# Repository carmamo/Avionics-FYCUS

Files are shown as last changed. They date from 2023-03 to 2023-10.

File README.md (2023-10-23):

<!-- Improved compatibility of back to top link: See: https://github.com/othneildrew/Best-README-Template/pull/73 -->

<!--
*** Thanks for checking out the Best-README-Template. If you have a suggestion
*** that would make this better, please fork the repo and create a pull request
*** or simply open an issue with the tag "enhancement".
*** Don't forget to give the project a star!
*** Thanks again! Now go create something AMAZING! :D
-->

<!-- PROJECT SHIELDS -->
<!--
*** I'm using markdown "reference style" links for readability.
*** Reference links are enclosed in brackets [ ] instead of parentheses ( ).
*** See the bottom of this document for the declaration of the reference variables
*** for contributors-url, forks-url, etc. This is an optional, concise syntax you may use.
*** https://www.markdownguide.org/basic-syntax/#reference-style-links
-->
[][contributors-url]
[][forks-url]
[][stars-url]
[][issues-url]
[][license-url]
[][linkedin-url]

<!-- PROJECT LOGO -->
<br />
<div align="center">
  <a href="https://github.com/carmamo/Avionics-FYCUS/">
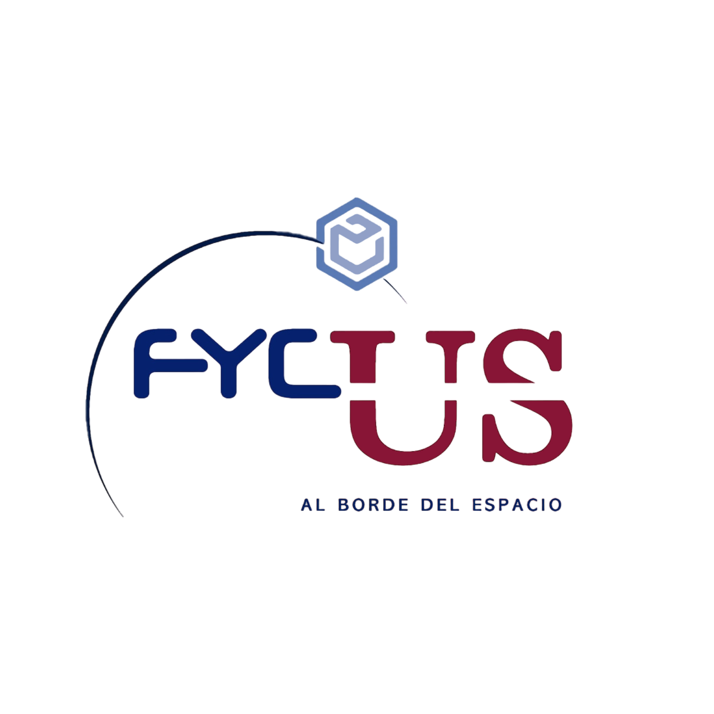
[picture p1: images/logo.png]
    
  </a>

<h3 align="center">Avionics FYCUS</h3>

  <p align="center">
    Hardware and Firmware for a 3U Cubesat
    <br />
    <a href="https://github.com/carmamo/Avionics-FYCUS"><strong>Explore the docs »</strong></a>
    <br />
    <br />
    <a href="https://github.com/carmamo/Avionics-FYCUS">View Demo</a>
    ·
    <a href="https://github.com/carmamo/Avionics-FYCUS/issues">Report Bug</a>
    ·
    <a href="https://github.com/carmamo/Avionics-FYCUS/issues">Request Feature</a>
  </p>
</div>

<!-- TABLE OF CONTENTS -->
<details>
  <summary>Table of Contents</summary>
  <ol>
    <li>
      <a href="#about-the-project">About The Project</a>
      <ul>
        <li><a href="#built-with">Built With</a></li>
      </ul>
    </li>
    <li>
      <a href="#getting-started">Getting Started</a>
      <ul>
        <li><a href="#prerequisites">Prerequisites</a></li>
        <li><a href="#installation">Installation</a></li>
      </ul>
    </li>
    <li><a href="#usage">Usage</a></li>
    <li><a href="#roadmap">Roadmap</a></li>
    <li><a href="#contributing">Contributing</a></li>
    <li><a href="#license">License</a></li>
    <li><a href="#contact">Contact</a></li>
    <li><a href="#acknowledgments">Acknowledgments</a></li>
  </ol>
</details>

<!-- ABOUT THE PROJECT -->
## About The Project
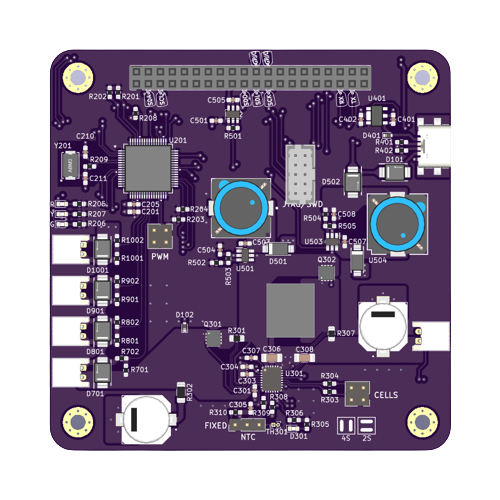
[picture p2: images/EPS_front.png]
Product front Screen Shot

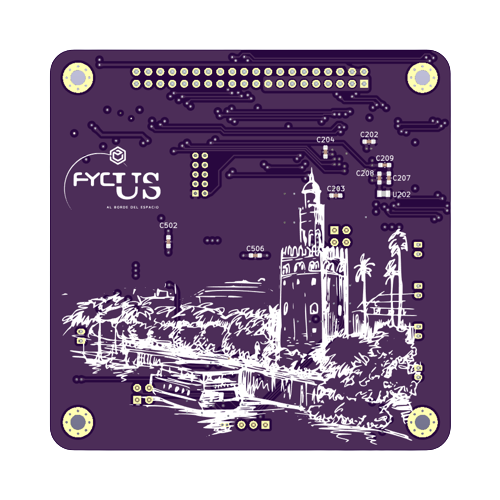
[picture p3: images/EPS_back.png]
Product back Screen Shot

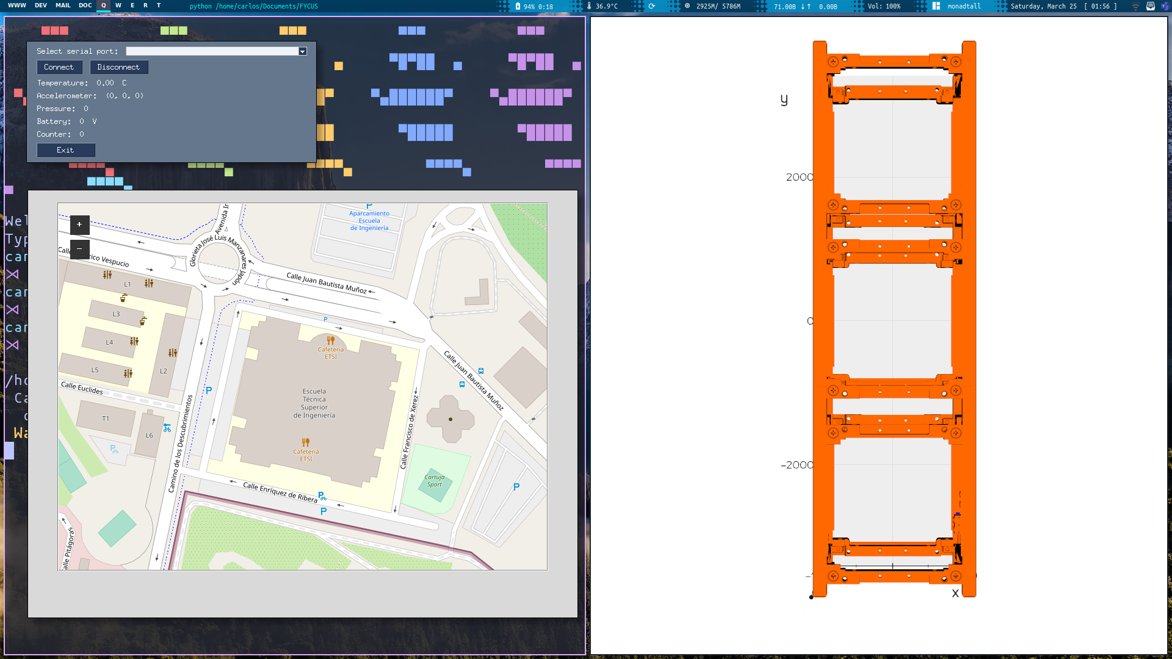
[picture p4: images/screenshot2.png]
Product gui Screen Shot
[][gui-screenshot]

This project involves the creation of the PCB and firmware for a 3U CubeSat, in collaboration with FYCUS, a team of passionate students at the University of Seville. Our mission is to design, manufacture and operate small satellites, and this project is a critical step in achieving that goal.

Our team will be responsible for the design and implementation of the PCB and firmware, which are essential components of the CubeSat's operation.

<p align="right">(<a href="#readme-top">back to top</a>)</p>

### Built With







<p align="right">(<a href="#readme-top">back to top</a>)</p>

<!-- GETTING STARTED -->
## Getting Started

This is an example of how you may give instructions on setting up your project locally.
To get a local copy up and running follow these simple example steps.

### Prerequisites

This is an example of how to list things you need to use the software and how to install them.
* npm
  ```sh
  npm install npm@latest -g
  ```

### Installation

1. Get a free API Key at [https://example.com](https://example.com)
2. Clone the repo
   ```sh
   git clone https://github.com/carmamo/Avionics-FYCUS.git
   ```
3. Install NPM packages
   ```sh
   npm install
   ```
4. Enter your API in `config.js`
   ```js
   const API_KEY = 'ENER YOUR API';
   ```

<p align="right">(<a href="#readme-top">back to top</a>)</p>

<!-- USAGE EXAMPLES -->
## Usage

Use this space to show useful examples of how a project can be used. Additional screenshots, code examples and demos work well in this space. You may also link to more resources.

_For more examples, please refer to the [Documentation](https://example.com)_

<p align="right">(<a href="#readme-top">back to top</a>)</p>

<!-- ROADMAP -->
## Roadmap

- [ ] Feature 1
- [ ] Feature 2
- [ ] Feature 3
    - [ ] Nested Feature

See the [open issues](https://github.com/carmamo/Avionics-FYCUS/issues) for a full list of proposed features (and known issues).

<p align="right">(<a href="#readme-top">back to top</a>)</p>

<!-- CONTRIBUTING -->
## Contributing

Contributions are what make the open source community such an amazing place to learn, inspire, and create. Any contributions you make are **greatly appreciated**.

If you have a suggestion that would make this better, please fork the repo and create a pull request. You can also simply open an issue with the tag "enhancement".
Don't forget to give the project a star! Thanks again!

1. Fork the Project
2. Create your Feature Branch (`git checkout -b feature/AmazingFeature`)
3. Commit your Changes (`git commit -m 'Add some AmazingFeature'`)
4. Push to the Branch (`git push origin feature/AmazingFeature`)
5. Open a Pull Request

<p align="right">(<a href="#readme-top">back to top</a>)</p>

<!-- LICENSE -->
## License

Distributed under the MIT License. See `LICENSE.txt` for more information.

<p align="right">(<a href="#readme-top">back to top</a>)</p>

<!-- CONTACT -->
## Contact

Your Name - [@twitter_handle](https://twitter.com/twitter_handle) - email@email_client.com

Project Link: [https://github.com/carmamo/Avionics-FYCUS](https://github.com/carmamo/Avionics-FYCUS)

<p align="right">(<a href="#readme-top">back to top</a>)</p>

<!-- ACKNOWLEDGMENTS -->
## Acknowledgments

* []()
* []()
* []()

<p align="right">(<a href="#readme-top">back to top</a>)</p>

<!-- MARKDOWN LINKS & IMAGES -->
<!-- https://www.markdownguide.org/basic-syntax/#reference-style-links -->
[contributors-shield]: https://img.shields.io/github/contributors/carmamo/Avionics-FYCUS.svg?style=for-the-badge
[contributors-url]: https://github.com/carmamo/Avionics-FYCUS/graphs/contributors
[forks-shield]: https://img.shields.io/github/forks/carmamo/Avionics-FYCUS.svg?style=for-the-badge
[forks-url]: https://github.com/carmamo/Avionics-FYCUS/network/members
[stars-shield]: https://img.shields.io/github/stars/carmamo/Avionics-FYCUS.svg?style=for-the-badge
[stars-url]: https://github.com/carmamo/Avionics-FYCUS/stargazers
[issues-shield]: https://img.shields.io/github/issues/carmamo/Avionics-FYCUS.svg?style=for-the-badge
[issues-url]: https://github.com/carmamo/Avionics-FYCUS/issues
[license-shield]: https://img.shields.io/github/license/carmamo/Avionics-FYCUS.svg?style=for-the-badge
[license-url]: https://github.com/carmamo/Avionics-FYCUS/blob/master/LICENSE.txt
[linkedin-shield]: https://img.shields.io/badge/-LinkedIn-black.svg?style=for-the-badge&logo=linkedin&colorB=555
[linkedin-url]: https://www.linkedin.com/company/fycus/?originalSubdomain=es
[gui-screenshot]: images/screenshot2.png
[product-screenshot-front]: images/EPS_front.png
[product-screenshot-back]: images/EPS_back.png

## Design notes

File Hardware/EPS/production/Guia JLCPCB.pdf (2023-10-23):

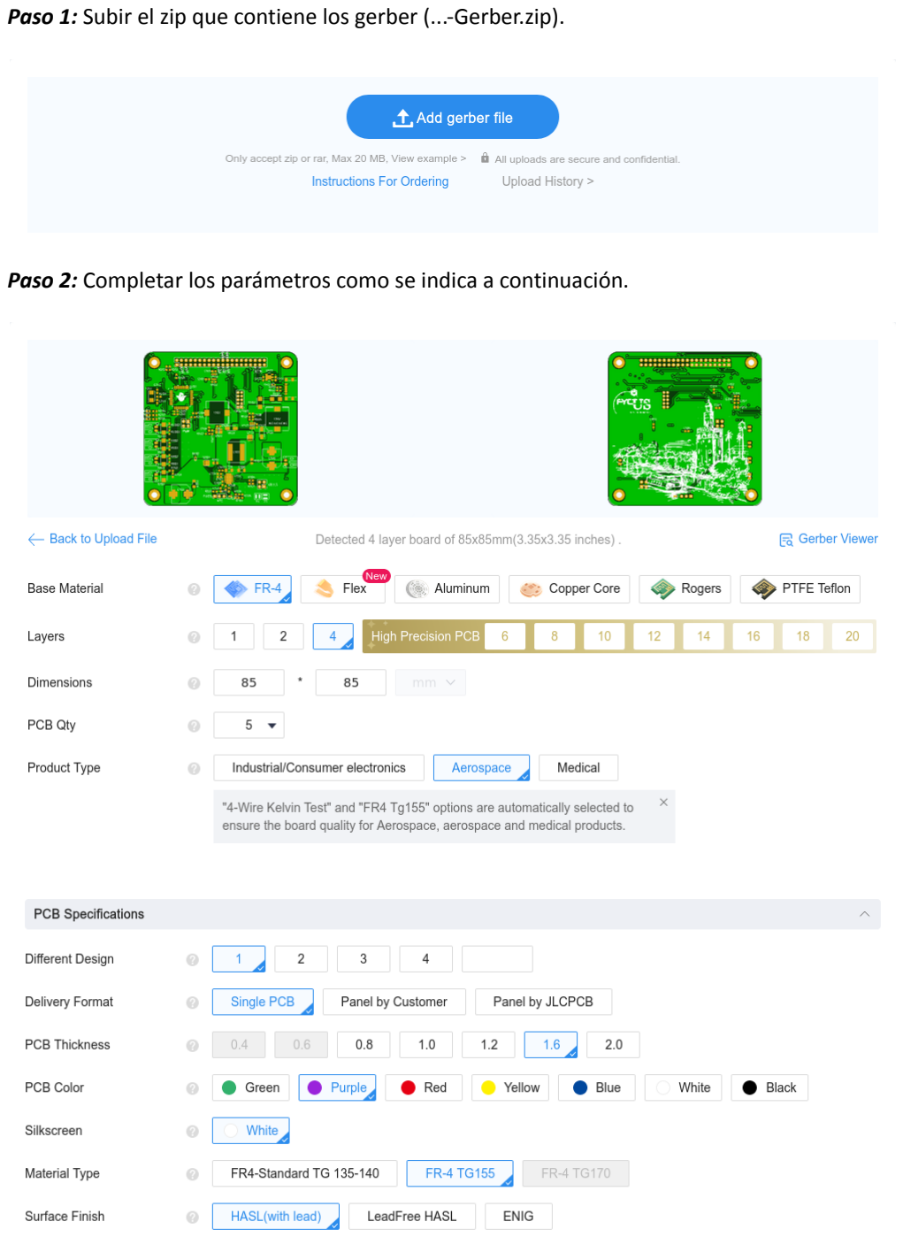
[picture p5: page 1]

Paso 1: Subir el zip que contiene los gerber (...-Gerber.zip).

Paso 2: Completar los parámetros como se indica a continuación.

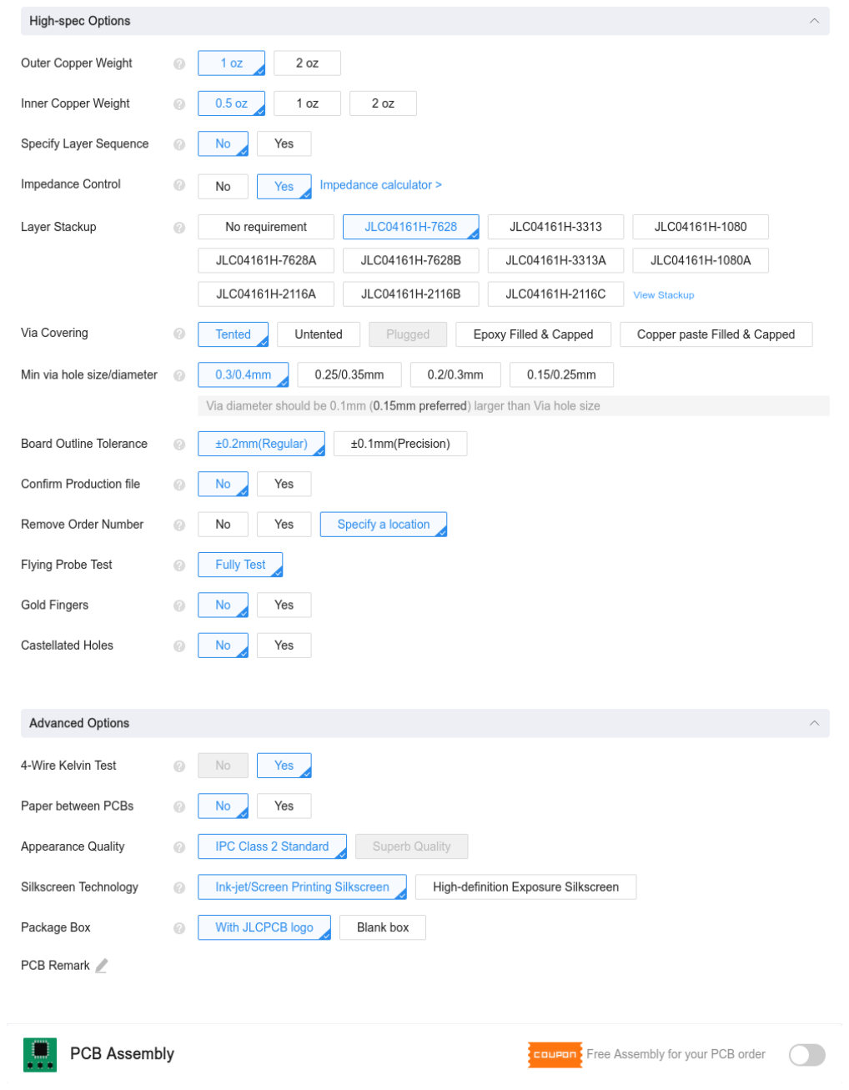
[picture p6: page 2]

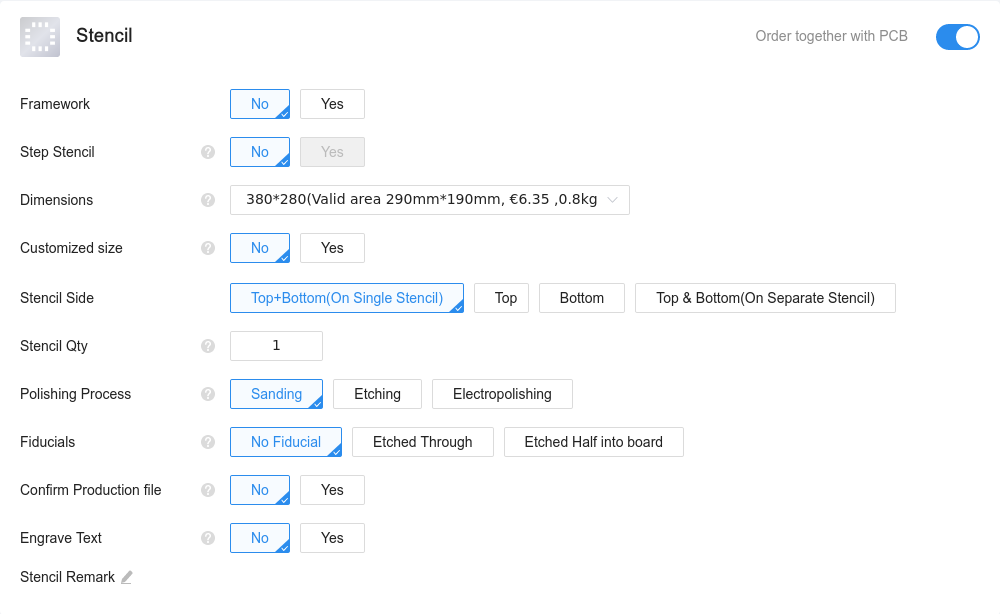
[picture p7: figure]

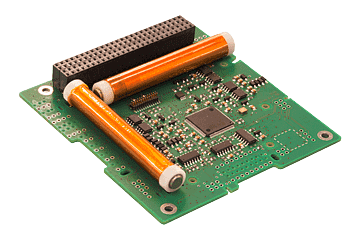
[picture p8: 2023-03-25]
images/screenshot.png

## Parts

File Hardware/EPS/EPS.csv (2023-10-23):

Component Count: | 107
Ref | Qnty | Digi-Key Part Number | Value | Cmp name | Footprint | Description
C201, C304, C401, C402, | 4 | 1276-1045-1-ND | 4.7uF | C | Capacitor_SMD:C_0603_1608Metric_Pad1.08x0.95mm_HandSolder | Unpolarized capacitor
C202, C203, C204, C205, C206, C209, C505, | 9 | 478-06036D104KAT2ACT-ND | 100nF | C | Capacitor_SMD:C_0603_1608Metric_Pad1.08x0.95mm_HandSolder | Unpolarized capacitor
C301, C303 | 9 | 1276-1935-1-ND | 100nF | C | Capacitor_SMD:C_0603_1608Metric_Pad1.08x0.95mm_HandSolder | Unpolarized capacitor
C207, C305, C501, | 3 | 1276-1034-1-ND | 1uF | C | Capacitor_SMD:C_0603_1608Metric_Pad1.08x0.95mm_HandSolder | Unpolarized capacitor
C208, C503, C507, | 3 | 399-17880-1-ND | 10nF | C | Capacitor_SMD:C_0603_1608Metric_Pad1.08x0.95mm_HandSolder | Unpolarized capacitor
C210, C211, | 2 | 1276-2134-1-ND | 6pF | C | Capacitor_SMD:C_0603_1608Metric_Pad1.08x0.95mm_HandSolder | Unpolarized capacitor
C302, C309, | 2 | 10-EEH-ZS1H151VCT-ND | 150uF | C_Polarized | EEHZS1H151V:CAP_EEHZS1H151V | Polarized capacitor
C306, C308, | 2 | 587-5960-1-ND | 10uF | C | Capacitor_SMD:C_1206_3216Metric_Pad1.33x1.80mm_HandSolder | Unpolarized capacitor
C307, | 1 | 399-C0603C223K4RAC7867CT-ND | 22nF | C | Capacitor_SMD:C_0603_1608Metric_Pad1.08x0.95mm_HandSolder | Unpolarized capacitor
C502, C506, | 2 | 490-3896-1-ND | 10uF | C | Capacitor_SMD:C_0603_1608Metric_Pad1.08x0.95mm_HandSolder | Unpolarized capacitor
C504, C508, | 2 | 1276-1274-1-ND | 22uF | C | Capacitor_SMD:C_0603_1608Metric_Pad1.08x0.95mm_HandSolder | Unpolarized capacitor
D101, D502, D701, D801, D901, D1001, | 6 | 150-LSM115JE3/TR13CT-ND | LSM115JE3_TR13 | LSM115JE3_TR13 | LSM115JE3_TR13:DIOM5436X330N | Schottky Diodes & Rectifiers Schottky
D102, | 1 | BZT585B24T-7DICT-ND | BZT585B24T-7 | D_Zener | Diode_SMD:D_SOD-523 | Zener diode
D201, | 1 | 160-1447-1-ND | LED_R | LED | LED_SMD:LED_0603_1608Metric | Light emitting diode
D202, | 1 | 160-1446-1-ND | LED_G | LED | LED_SMD:LED_0603_1608Metric | Light emitting diode
D203, | 2 | 160-1448-1-ND | LED_YL | LED | LED_SMD:LED_0603_1608Metric | Light emitting diode
D401, | 1 | 1727-3838-1-ND | PESD5V0S1BB_115 | D_TVS | Diode_SMD:D_SOD-523 | Bidirectional transient-voltage-suppression diode
D501, | 2 | B230A-FDICT-ND | B230A-13-F | B230A-13-F | B230A-13-F:DIOM5226X230N | Schottky Diode 2A 30V 0.5Vf SMA Diodes Inc B230A-13-F, SMT Schottky Diode, 30V 2A, 2-Pin DO-214AC
J201, | 1 | 1175-1627-ND | Conn_ARM_JTAG_SWD_10 | Conn_ARM_JTAG_SWD_10 | digikey-footprints:PinHeader_2x5_P1.27mm_Drill.7mm | Cortex Debug Connector, standard ARM Cortex-M SWD and JTAG interface
J401, | 1 | 2073-USB4135-GF-ACT-ND | USB_C_Receptacle_PowerOnly_6P | USB_C_Receptacle_PowerOnly_6P | Connector_USB:USB_C_Receptacle_GCT_USB4135-GF-A_6P_TopMnt_Horizontal | USB Power-Only 6P Type-C Receptacle connector
J701, J801, J901, J1001, J1101, | 50 | 455-1719-ND | Conn_01x02 | Conn_01x02 | Connector_JST:JST_PH_S2B-PH-K_1x02_P2.00mm_Horizontal
 | 50 | 455-1165-ND | PHR-2 | CONN RCPT HSG 2POS 2.00MM |  | CONN RCPT HSG 2POS 2.00MM
 | 100 | 455-2148-1-ND | SPH-002T-P0.5L | CONN SOCKET 24-28AWG CRIMP TIN |  | CONN SOCKET 24-28AWG CRIMP TIN
L301, | 1 | 4652-XAL1060-472MEC-ND / 240-MHE06034R7M-10CT-ND | 4.7uH | L | XAL1060-222MEB:XAL1060222MEB | Inductor
L501, | 1 | 445-SLF12555T-100M3R4-PFCT-ND | 10uH | L | SLF12555T-100M3R4-PF:SLF12555T | Inductor
L502, | 1 | 445-174404-1-ND | 15uH | L | SLF12565T-150M4R2-PF:SLF12565 | Inductor
Q301, Q302, | 2 | RQ3G100GNTBCT-ND | RQ3G100GNTB | RQ3G100GNTB | RQ3G100GNTB:RQ3G100GNTB | Nch 40V 27A Power MOSFET
R201, R202, R203, R204, | 4 | 1712-CPF-A-0603B4K7ECT-ND | 4.7k | R | Resistor_SMD:R_0603_1608Metric_Pad0.98x0.95mm_HandSolder | Resistor
R205, R206, | 2 | A102228CT-ND | 1.3k | R | Resistor_SMD:R_0603_1608Metric_Pad0.98x0.95mm_HandSolder | Resistor
R207, R305, | 2 | 1712-CPF-A-0603B1K2ECT-ND | 1.2k | R | Resistor_SMD:R_0603_1608Metric_Pad0.98x0.95mm_HandSolder | Resistor
R208, R309, R310, R501, | 4 | A121523CT-ND | 10k | R | Resistor_SMD:R_0603_1608Metric_Pad0.98x0.95mm_HandSolder | Resistor
R209, R702, R802, R902, R1002, | 5 | A129694CT-ND | 3.3k | R | Resistor_SMD:R_0603_1608Metric_Pad0.98x0.95mm_HandSolder | Resistor
R301, R307, | 2 | 2019-UR73D2ATTD10L0FCT-ND | 10m | R | Resistor_SMD:R_0805_2012Metric_Pad1.20x1.40mm_HandSolder | Resistor
R302, | 1 | 2019-RK73H2HTTE2R49FCT-ND | 2.49 | R | Resistor_SMD:R_2010_1608Metric_Pad0.98x0.95mm_HandSolder | Resistor
R303, R304, R306, R502, | 4 | 408-2101-1-ND | 100k | R | Resistor_SMD:R_0603_1608Metric_Pad0.98x0.95mm_HandSolder | Resistor
R308, | 1 | 541-63.4KHCT-ND | 63.4k | R | Resistor_SMD:R_0603_1608Metric_Pad0.98x0.95mm_HandSolder | Resistor
R401, R402, | 2 | RG16P5.1KBCT-ND | 5.1k | R | Resistor_SMD:R_0603_1608Metric_Pad0.98x0.95mm_HandSolder | Resistor
R503, | 1 | RG16P32.4KBCT-ND | 32.4k | R | Resistor_SMD:R_0603_1608Metric_Pad0.98x0.95mm_HandSolder | Resistor
R504, | 1 | RG16P91.0KBCT-ND | 91k | R | Resistor_SMD:R_0603_1608Metric_Pad0.98x0.95mm_HandSolder | Resistor
R505, | 1 | RMCF0603FT17K4CT-ND | 17.4k | R | Resistor_SMD:R_0603_1608Metric_Pad0.98x0.95mm_HandSolder | Resistor
R701, R801, R901, R1001, | 4 | A129703CT-ND | 18k | R | Resistor_SMD:R_0603_1608Metric_Pad0.98x0.95mm_HandSolder | Resistor
TH301, | 1 | 2259-BN35-3H103FB-50-ND | 10k | Thermistor_NTC | Connector_PinHeader_1.00mm:PinHeader_1x02_P1.00mm_Vertical | Temperature dependent resistor, negative temperature coefficient
U201, | 1 | 497-STM32L431RCT6CT-ND | STM32L431RCT | STM32L431RCT | STM32L431RCT:LQFP-64
U202, | 1 | 240-2399-1-ND | HZ0805E601R-10 | HZ0805E601R-10 | HZ0805E601R-10:BEADC2012X90N | FERRITE BEAD 600 OHM 0805 1LN
U301, | 1 | LTC4162EUFD-L41M#PBF-ND | LTC4162EUFD-L41M#PBF | LTC4162EUFD-L41#PBF | LTC4162EUFD-L41_PBF:QFN50P500X400X80-29N
U301, | 1 | 505-LTC4162EUFD-LADM#PBF-ND | LTC4162EUFD-LADM#PBF | LTC4162EUFD-L41#PBF | LTC4162EUFD-L41_PBF:QFN50P500X400X80-29N
U401, | 1 | AP7361C-25Y5-13DICT-ND | AP7361C-33Y5-13 | AP7361C-25Y5-13 | AP7361C-25Y5-13:AP7361C25Y513 | LDO Voltage Regulators 1A LDO Reg w/Enable 2.5V 6.5Vin 800mW
U501, U503, | 2 | 1028-RT8258GECT-ND | RT8258GE | RT8258GE | RT8258GE:SOT94P279X130-6N | IC REG BUCK ADJ 1.2A SOT23-6
U502, | 1 | 296-34970-1-ND | TPS27081ADDCR | TPS27081ADDCR | digikey-footprints:SOT-23-6 | IC LOAD SW HIGH SIDE 6SOT
Y201, | 1 | 644-1132-1-ND | NX5032GA-8.000M-STD-CSU-1 | NX5032GA-8.000M-STD-CSU-1 | NX5032GA-8.000M:XTAL_NX5032_NDK

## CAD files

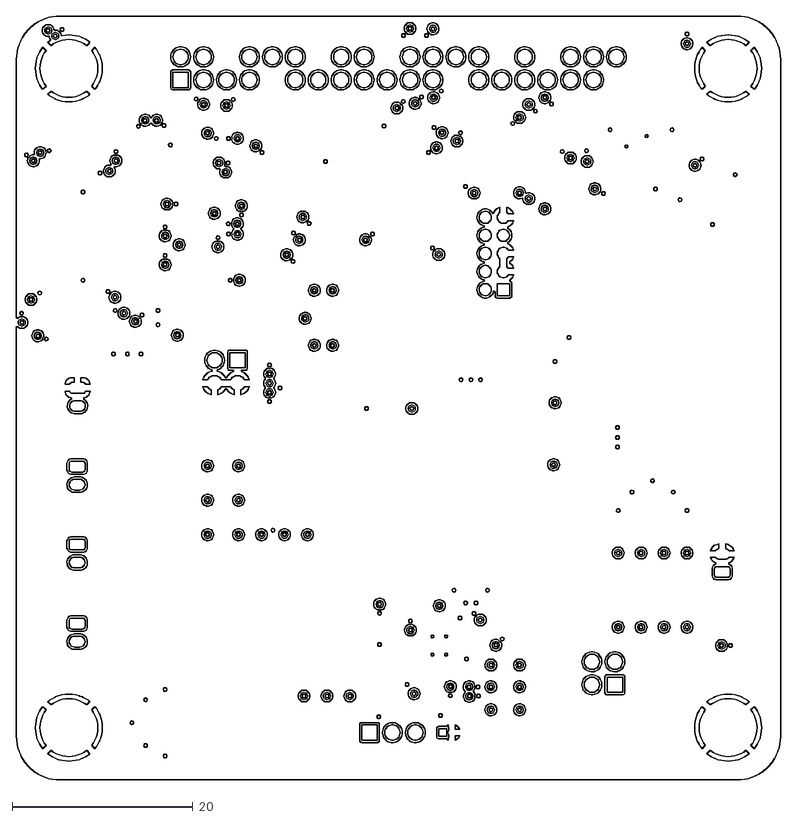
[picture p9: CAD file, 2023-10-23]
Hardware/EPS/production/EPS-GND2_Cu.dxf
84.6 x 84.6

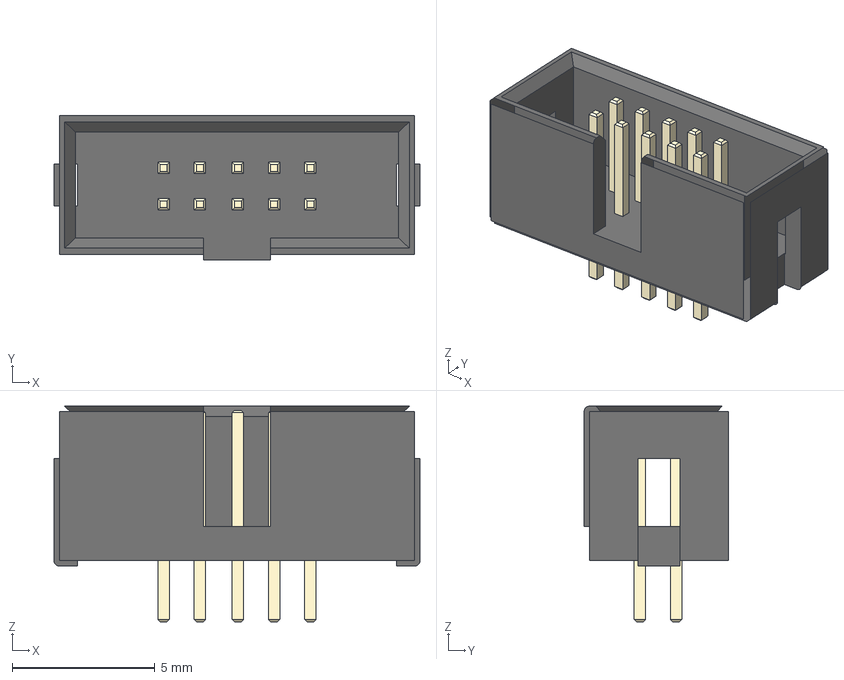
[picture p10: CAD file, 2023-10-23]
Hardware/KiCAD_Libs/3220-10-0100-00/3D/3220-10-0100-00.stp
12.8 x 5.24 x 7.55 mm
Linear Pattern 01
Pins:1

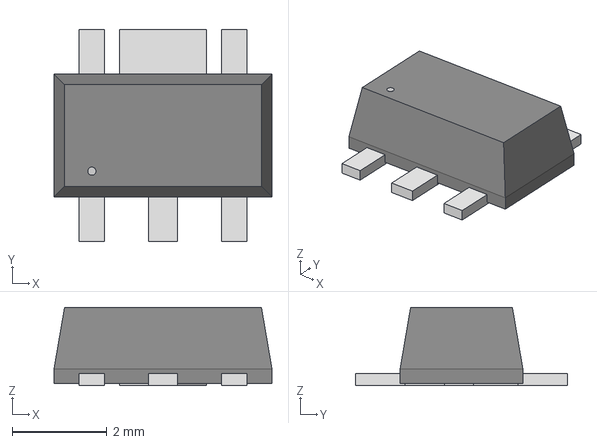
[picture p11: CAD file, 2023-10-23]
Hardware/KiCAD_Libs/AP7361C-25Y5-13/3D/SOT89-5_DIO.step
4.60 x 4.47 x 1.65 mm

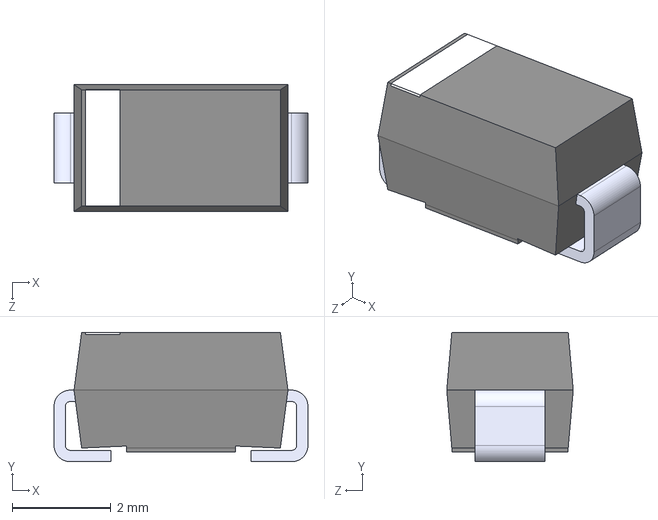
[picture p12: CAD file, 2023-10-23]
Hardware/KiCAD_Libs/B230A-13-F/3D/B340A-13-F.STEP
5.14 x 2.62 x 2.56 mm

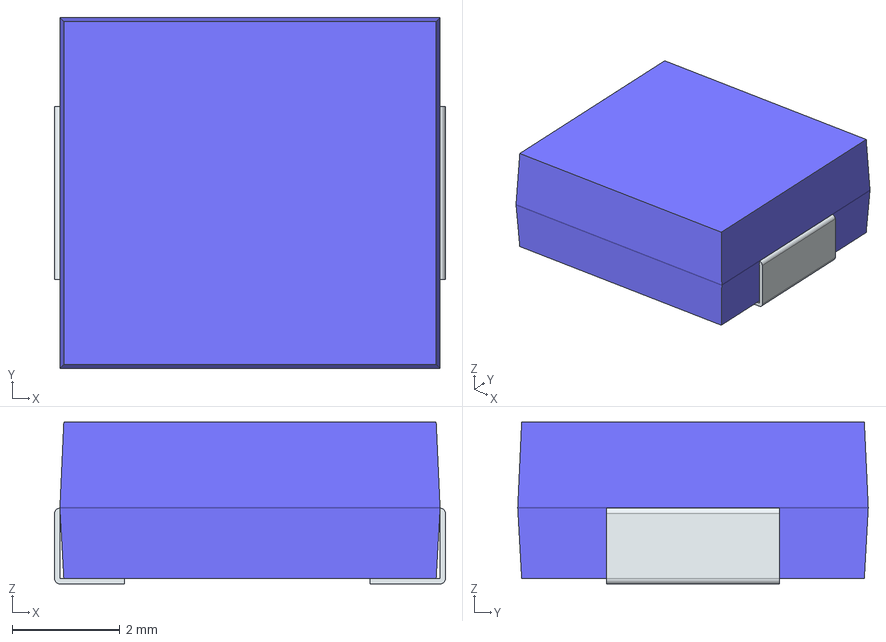
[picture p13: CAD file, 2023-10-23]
Hardware/KiCAD_Libs/CDMC6D28NP-2R2MC/3D/CDMC6D28NP-2R2MC.stp
7.25 x 6.50 x 3.00 mm
FilletPin1
FilletPin2

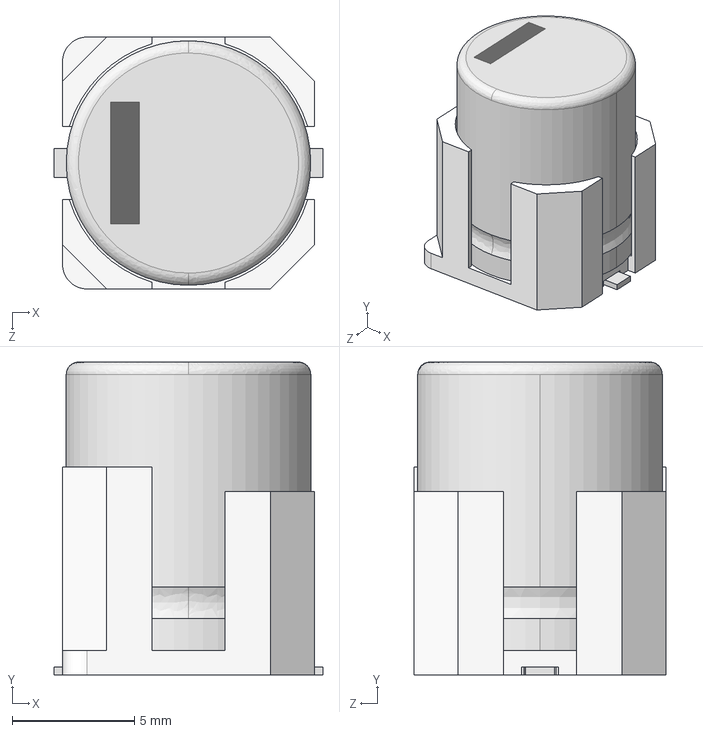
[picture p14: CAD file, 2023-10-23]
Hardware/KiCAD_Libs/EEHZS1H151V/3D/EEHZS1H151V.STEP
11.0 x 12.8 x 10.3 mm

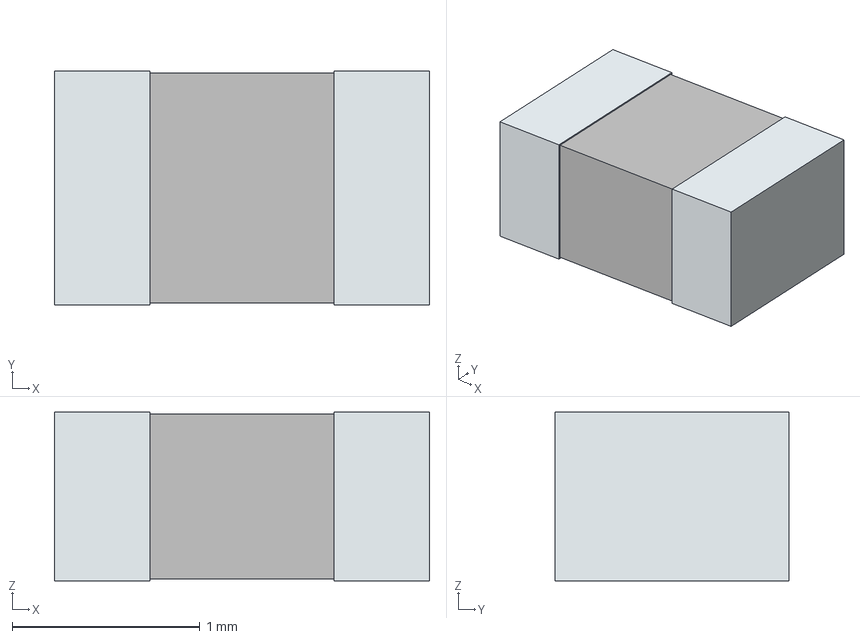
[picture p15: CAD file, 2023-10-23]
Hardware/KiCAD_Libs/HZ0805E601R-10/3D/HZ0805E601R-10.stp
2.00 x 1.25 x 0.9 mm
term1
term2

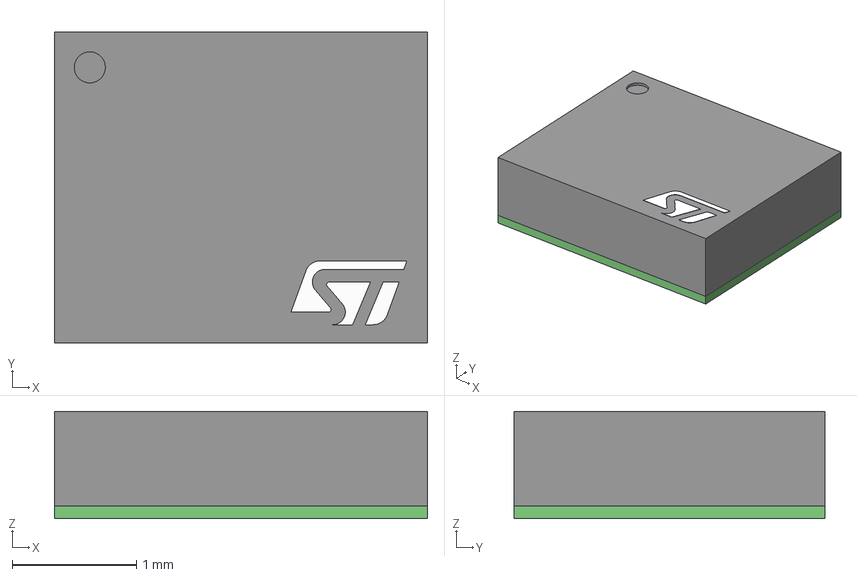
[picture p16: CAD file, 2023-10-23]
Hardware/KiCAD_Libs/IMU_LSM6DSOTR/eec.models/STMicroelectronics_-_LSM6DSOTR.step
3.00 x 2.50 x 0.863 mm
base
logo
terminals

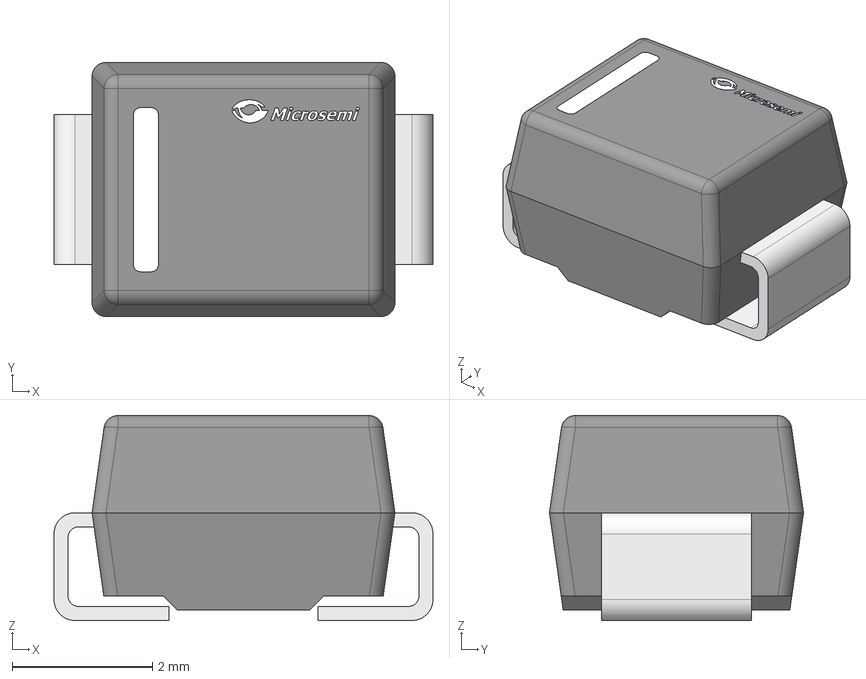
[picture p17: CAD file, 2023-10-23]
Hardware/KiCAD_Libs/LSM115JE3_TR13/3D/TR13.step
5.40 x 3.62 x 2.92 mm

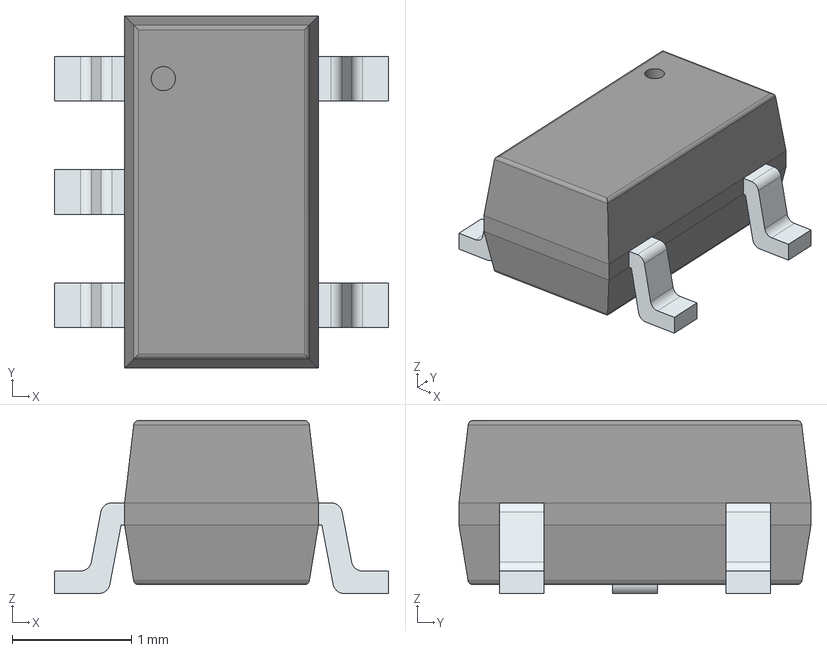
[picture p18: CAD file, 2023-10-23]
Hardware/KiCAD_Libs/LT1930ES5#TRMPBF/3D/LT1930ES5#TRMPBF.stp
2.80 x 2.95 x 1.45 mm
PinsArrayL
PinsArrayR

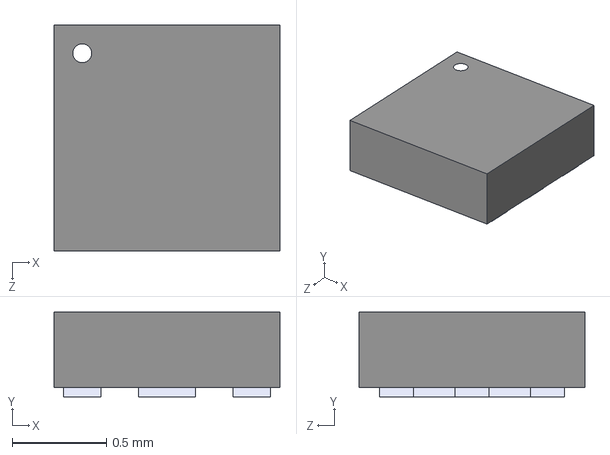
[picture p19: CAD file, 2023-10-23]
Hardware/KiCAD_Libs/NCP176AMX330TCG/3D/NCP176AMX330TCG.STEP
1.20 x 0.45 x 1.20 mm

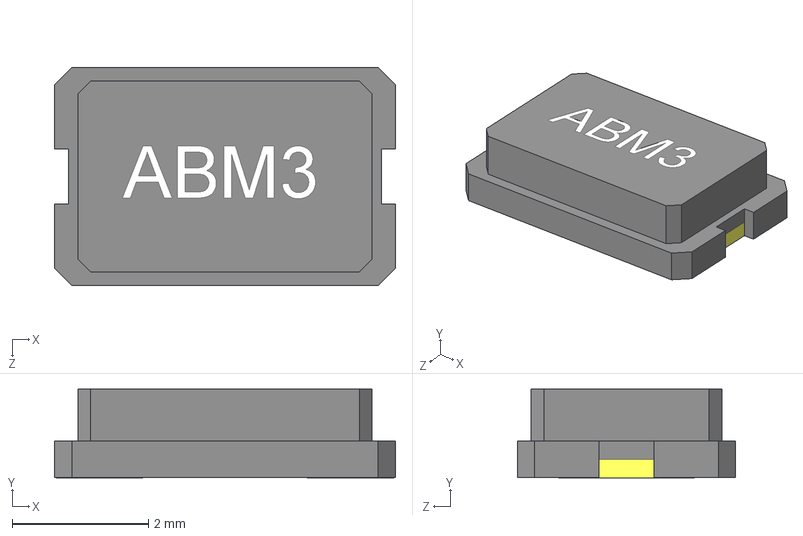
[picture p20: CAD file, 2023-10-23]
Hardware/KiCAD_Libs/NX5032GA-8.000M/3D/ABM3-8.000MHZ-D2Y-T--3DModel-STEP-400430.STEP
5.00 x 1.30 x 3.20 mm

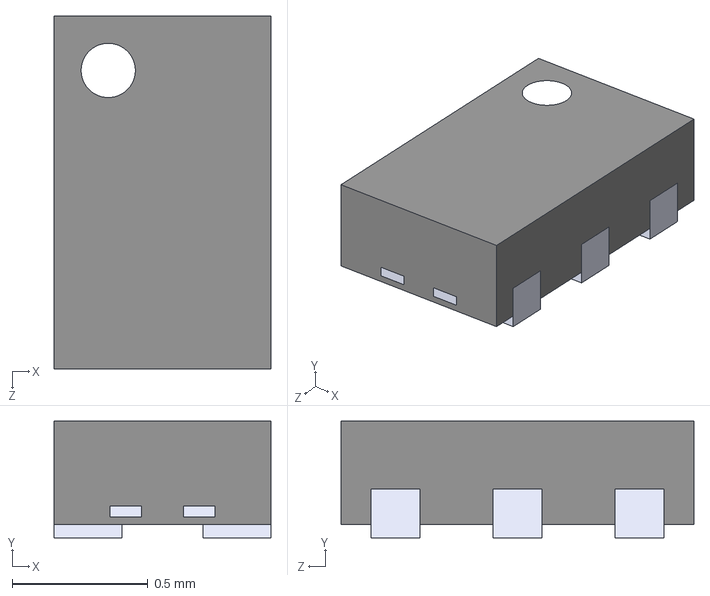
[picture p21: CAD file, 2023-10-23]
Hardware/KiCAD_Libs/PESD3V3L4BHCYL/3D/PESD3V3L4BHCYL.STEP
0.8 x 0.43 x 1.30 mm

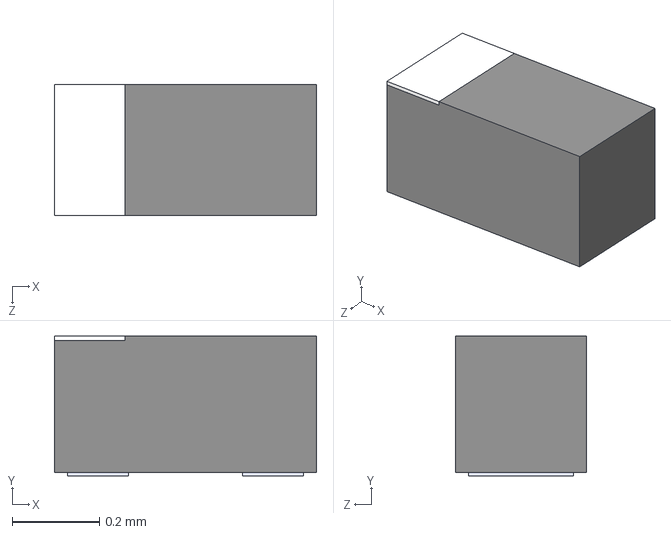
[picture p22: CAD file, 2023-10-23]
Hardware/KiCAD_Libs/PESD5V0H1BSFYL/3D/PESD5V0H1BSF.STEP
0.6 x 0.32 x 0.3 mm

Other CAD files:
Hardware/KiCAD_Libs/RM-VT02/3D/RM-VT02.stp
Hardware/KiCAD_Libs/RQ3G100GNTB/3D/RQ3G100GNTB.stp
Hardware/KiCAD_Libs/SSW-120-03-G-D/3D/SSW-120-03-G-D.stp
Hardware/KiCAD_Libs/STM32L431RCT6/3D/STM32L431RCT6.stp
Hardware/EPS/production/EPS-B_Cu.dxf
Hardware/EPS/production/EPS-B_Mask.dxf
Hardware/EPS/production/EPS-B_Paste.dxf
Hardware/EPS/production/EPS-B_Silkscreen.dxf
Hardware/EPS/production/EPS-Edge_Cuts.dxf
Hardware/EPS/production/EPS-F_Cu.dxf
Hardware/EPS/production/EPS-F_Mask.dxf
Hardware/EPS/production/EPS-F_Paste.dxf
Hardware/EPS/production/EPS-F_Silkscreen.dxf
Hardware/EPS/production/EPS-GND1_Cu.dxf
Hardware/KiCAD_Libs/0530480210/3D/0530480210.stp
Hardware/KiCAD_Libs/1206L380SLTHYR/3D/1206L380SLTHYR.stp
Hardware/KiCAD_Libs/87831-1021/3D/87831-1021.stp
Hardware/KiCAD_Libs/MHE06033R3M-10/3D/MHE06033R3M-10.stp
Hardware/KiCAD_Libs/SLF12555T-100M3R4-PF/3D/SLF12555T-100M3R4-PF.stp
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

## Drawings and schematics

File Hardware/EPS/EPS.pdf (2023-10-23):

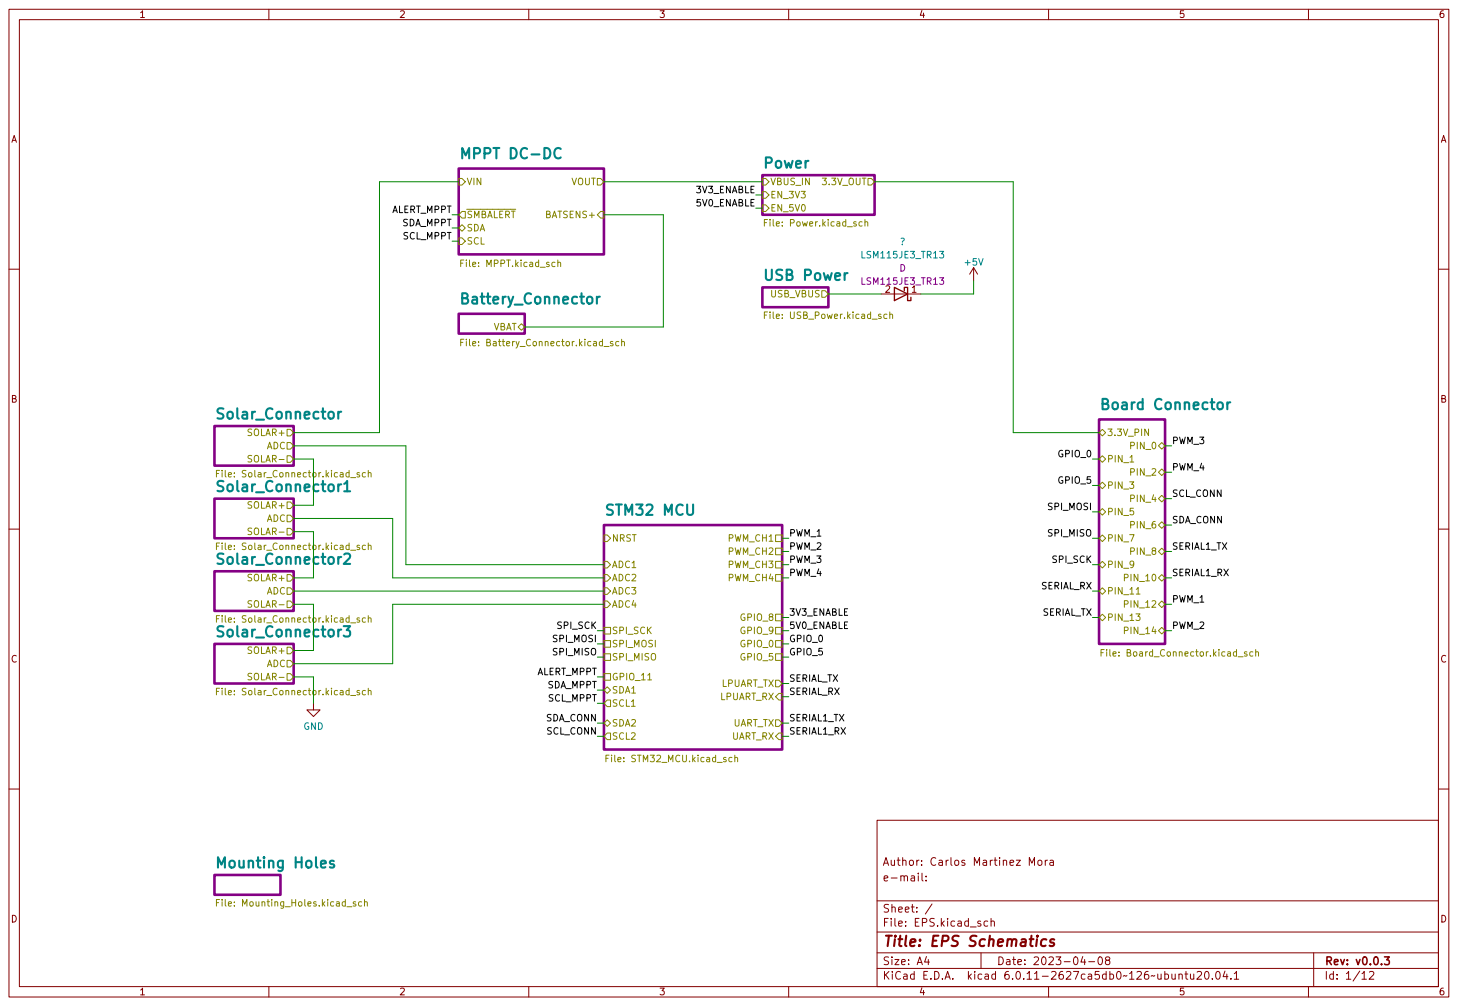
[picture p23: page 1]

File: Power.kicad_sch SOLAR- SOLAR+ ADC Solar_Connector2

File: Board_Connector.kicad_sch SOLAR- SOLAR+ ADC Solar_Connector

File: Solar_Connector.kicad_sch SOLAR- SOLAR+ ADC Solar_Connector3

Id: 1/12 Title: EPS Schematics

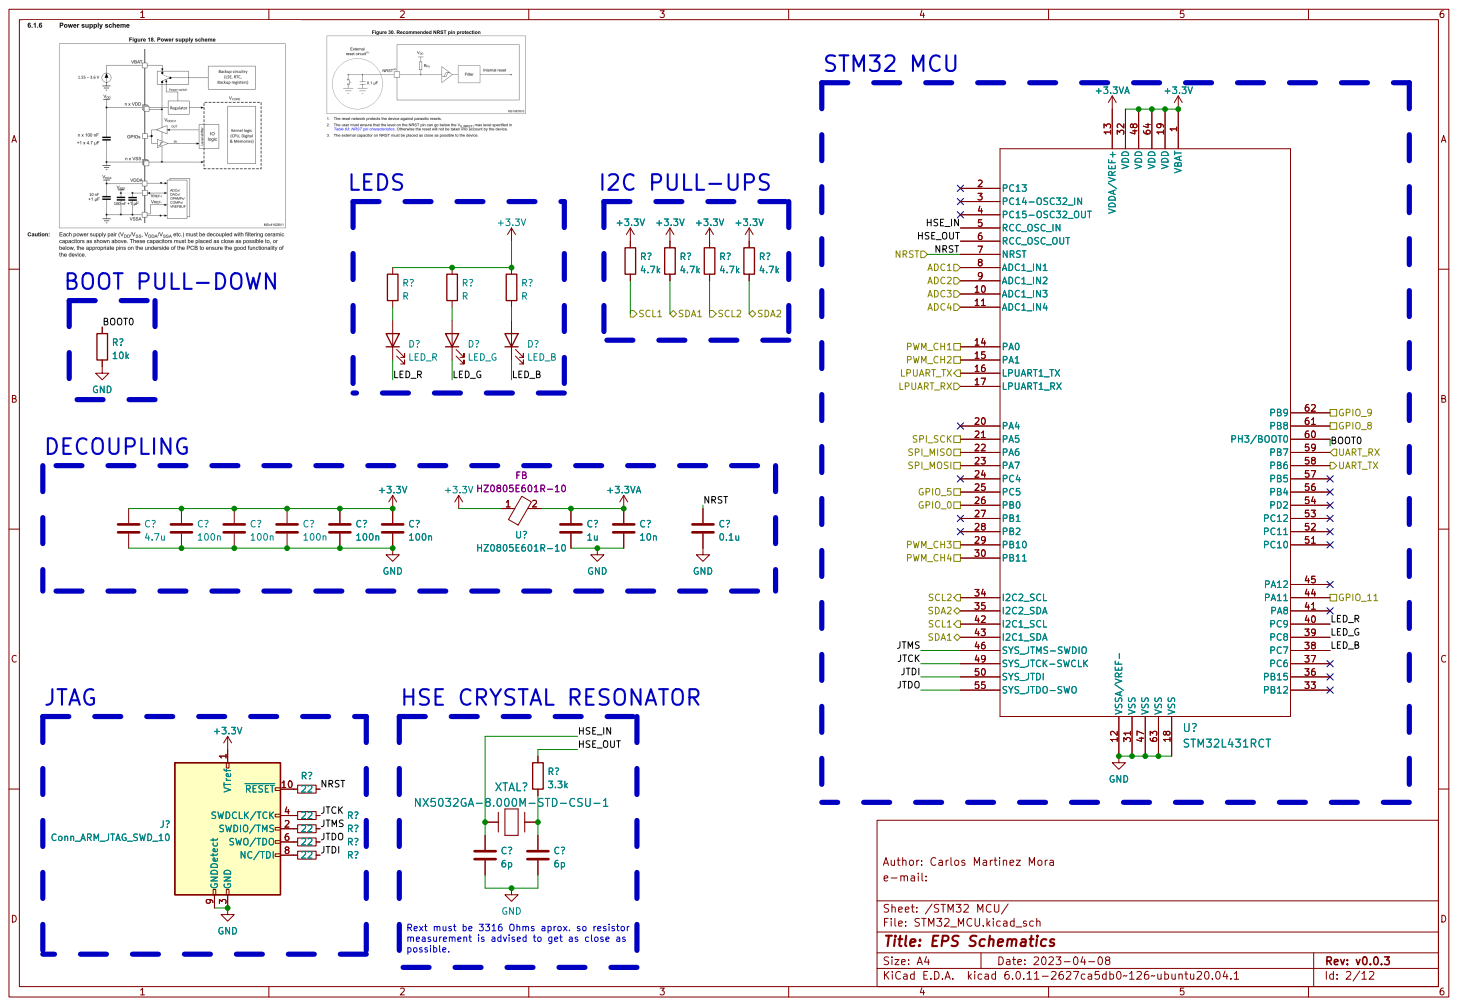
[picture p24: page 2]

1 ADC1_IN3 10 ADC1_IN4 11 VSSA/VREF- 12 VDDA/VREF+ 13 PA0

3 SWDCLK/TCK 4 SWO/TDO 6 NC/TDI 8 GNDDetect 9

3 SWDCLK/TCK 4 SWO/TDO 6 NC/TDI 8 GNDDetect 9 GND

File: STM32_MCU.kicad_sch Sheet: /STM32 MCU/ e-mail: Author: Carlos Martinez Mora

Id: 2/12 Title: EPS Schematics

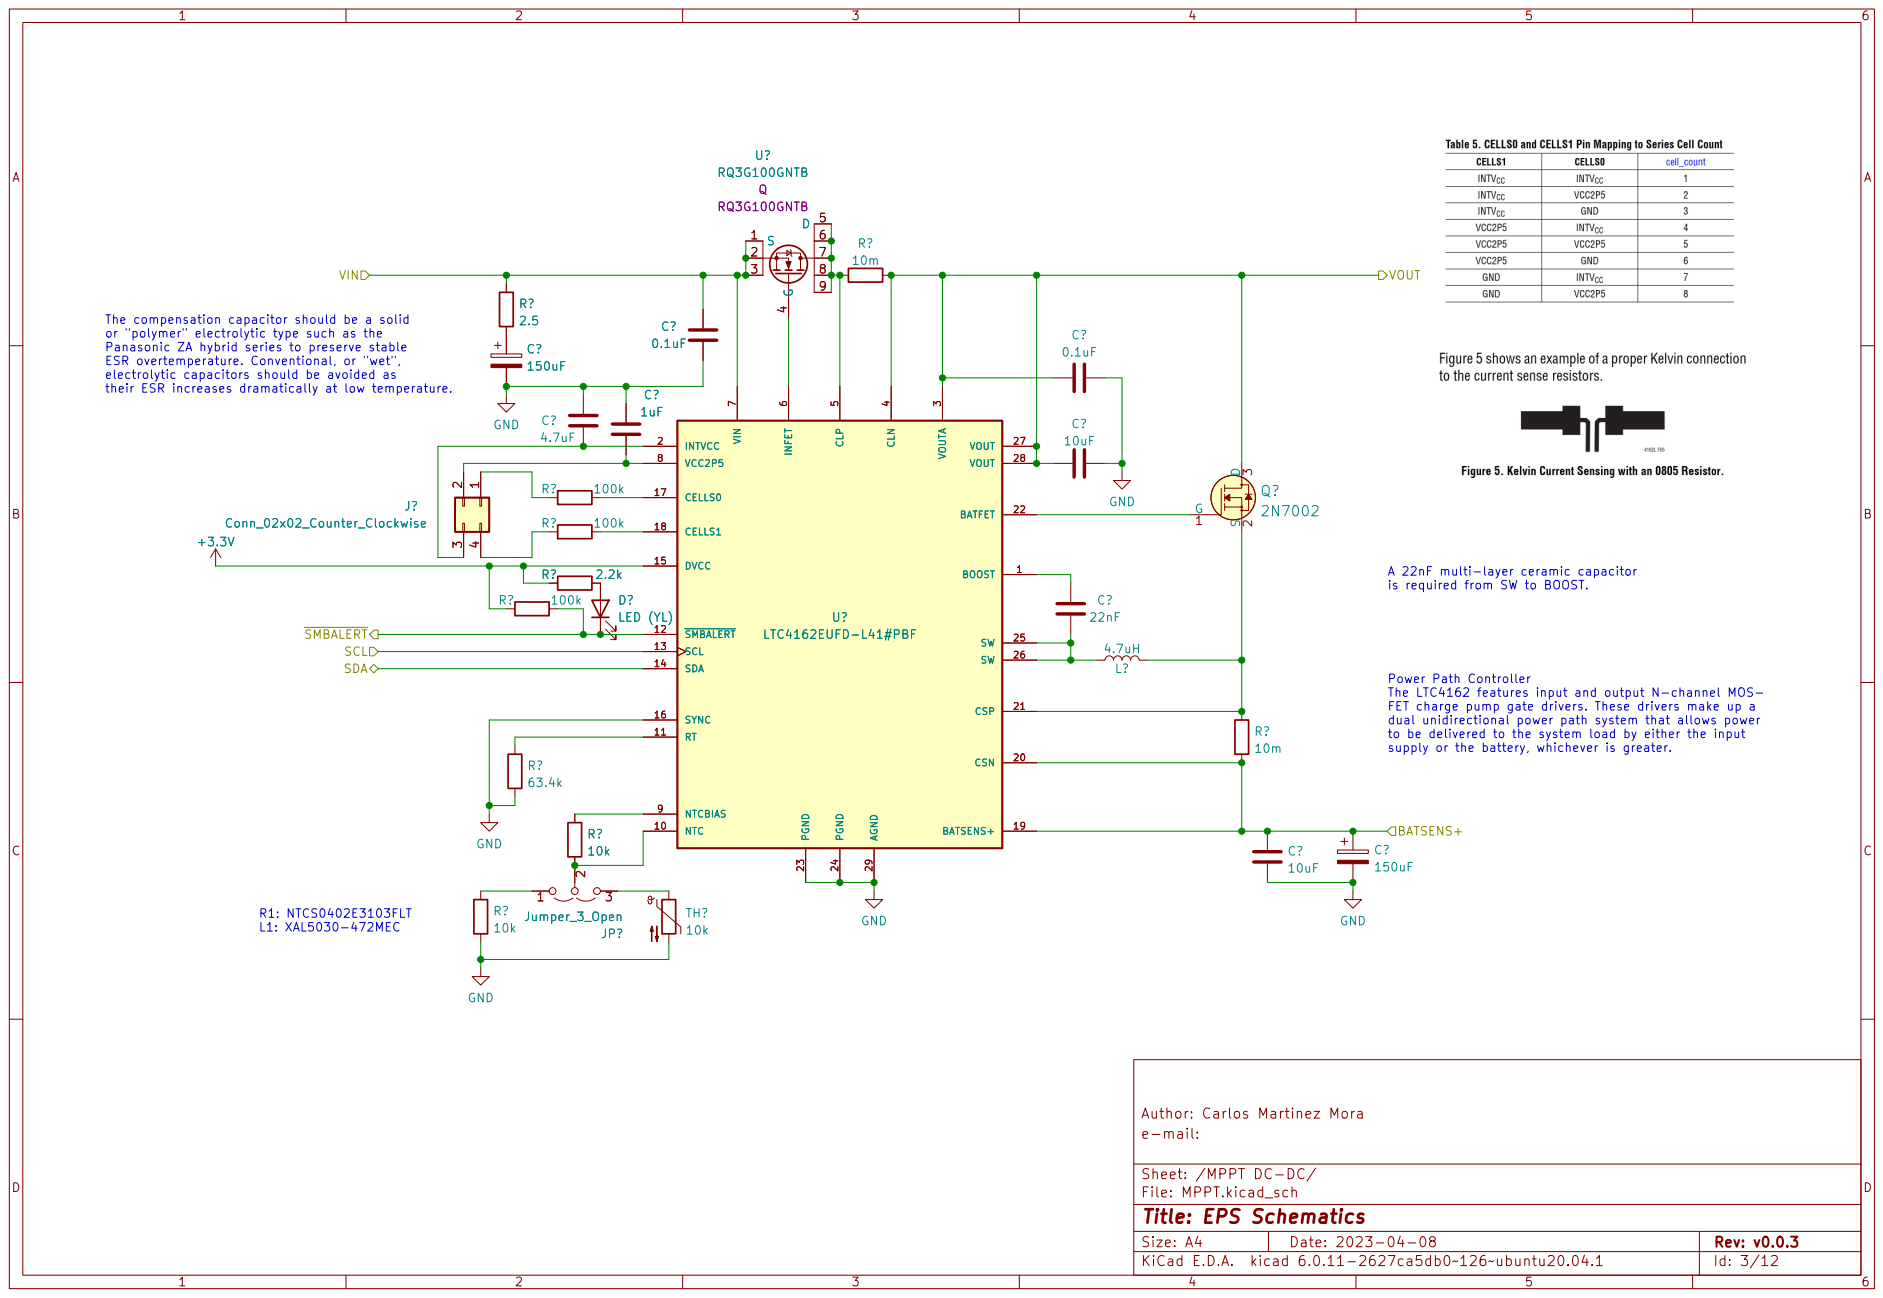
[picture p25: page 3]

supply or the battery, whichever is greater. R1: NTCS0402E3103FLT

Id: 3/12 Title: EPS Schematics

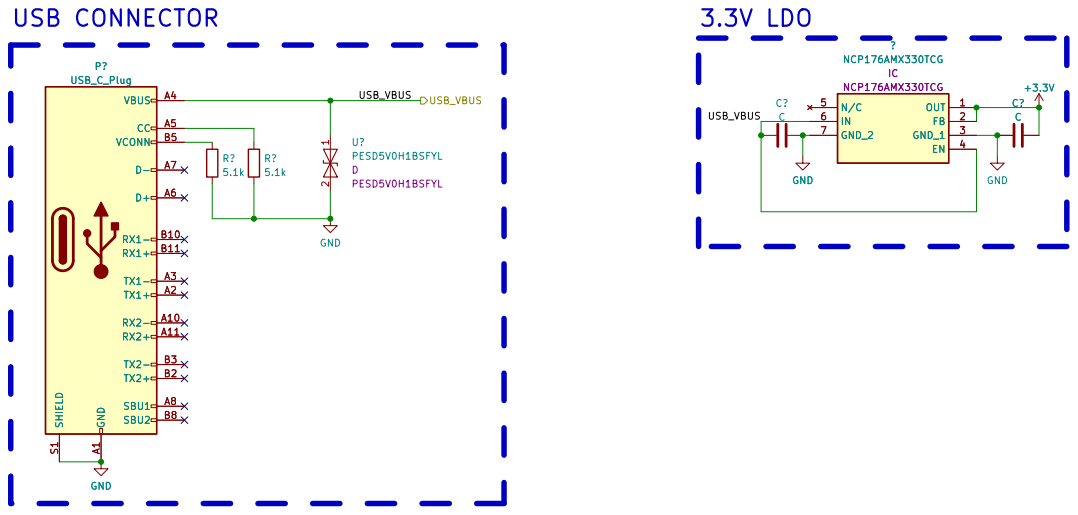
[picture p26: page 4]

File: USB_Power.kicad_sch Sheet: /USB Power/ e-mail: Author: Carlos Martinez Mora

Id: 4/12 Title: EPS Schematics

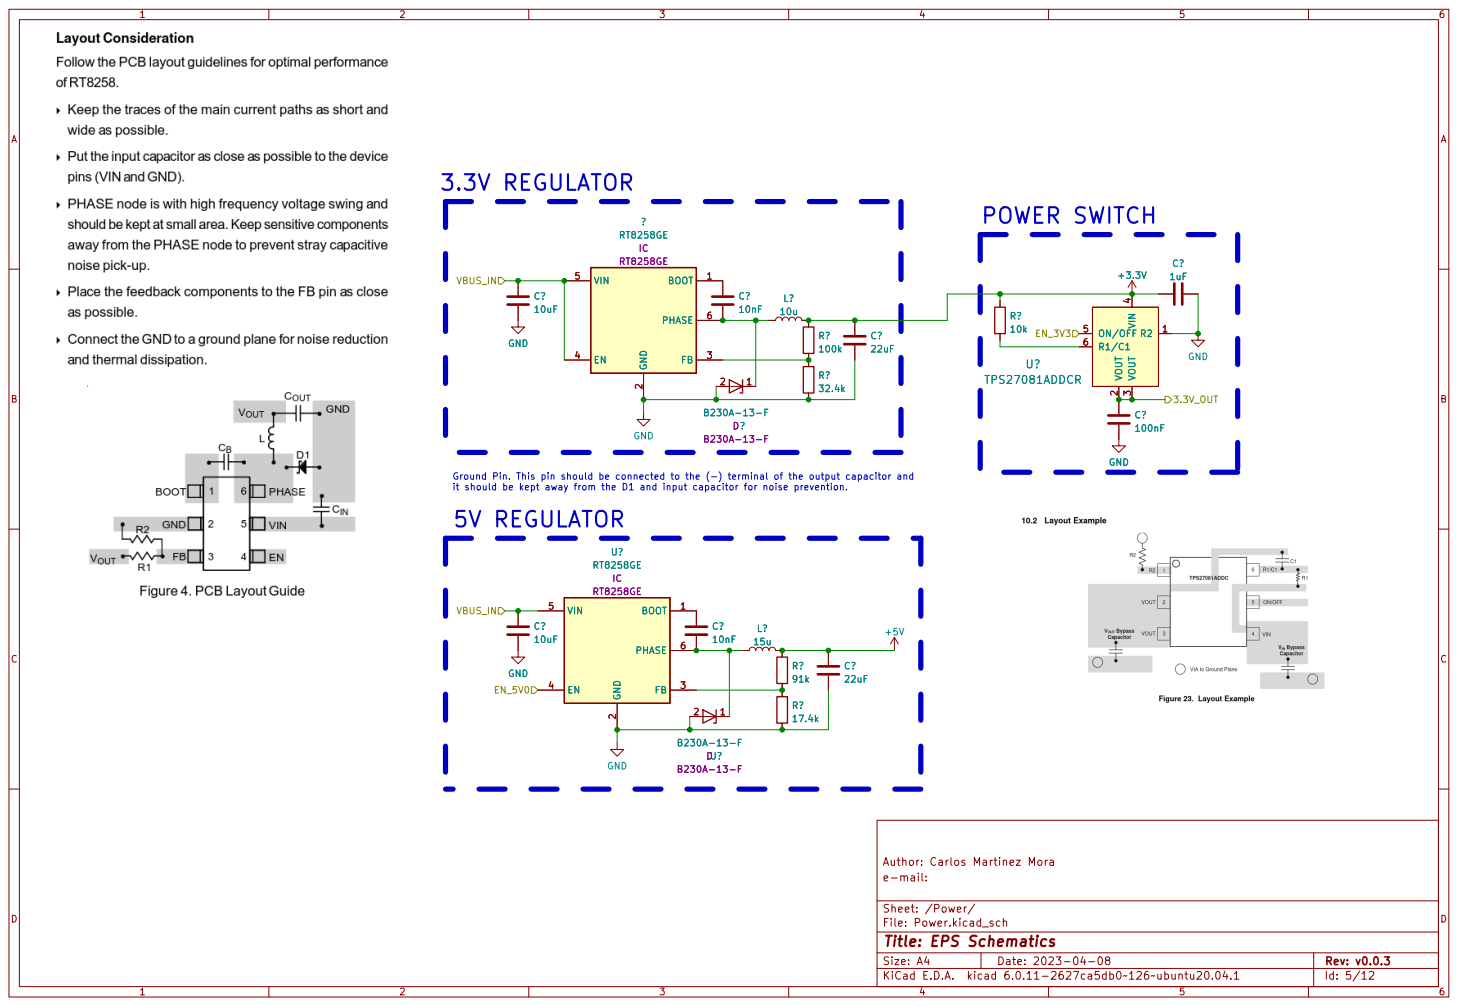
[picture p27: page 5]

Id: 5/12 Title: EPS Schematics

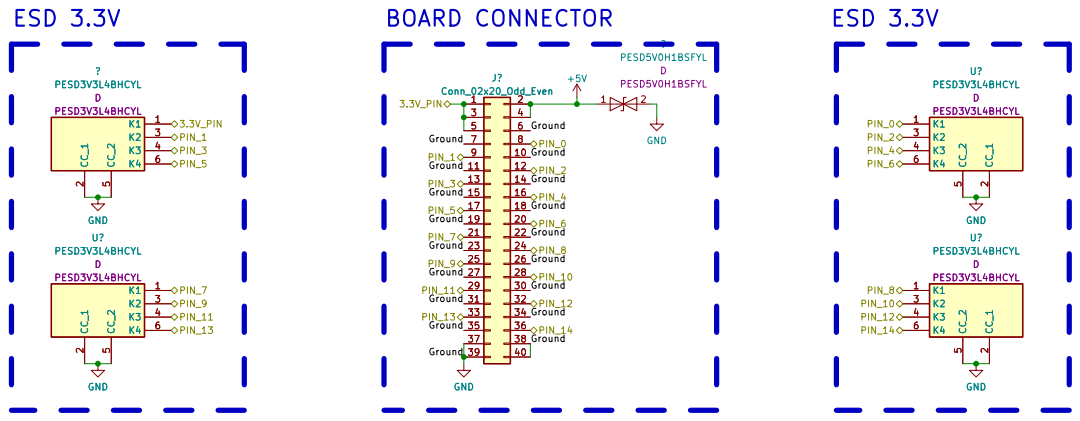
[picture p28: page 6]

Id: 6/12 Title: EPS Schematics

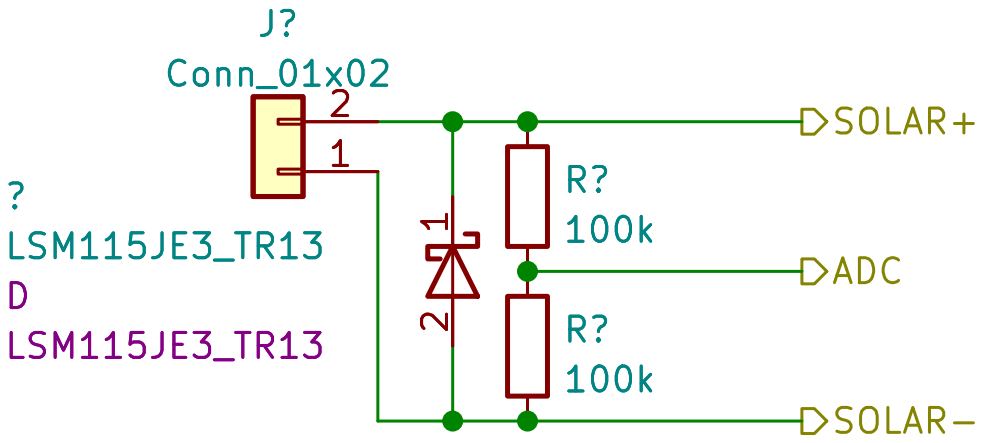
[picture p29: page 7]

File: Solar_Connector.kicad_sch Sheet: /Solar_Connector/ e-mail: Author: Carlos Martinez Mora

Id: 7/12 Title: EPS Schematics

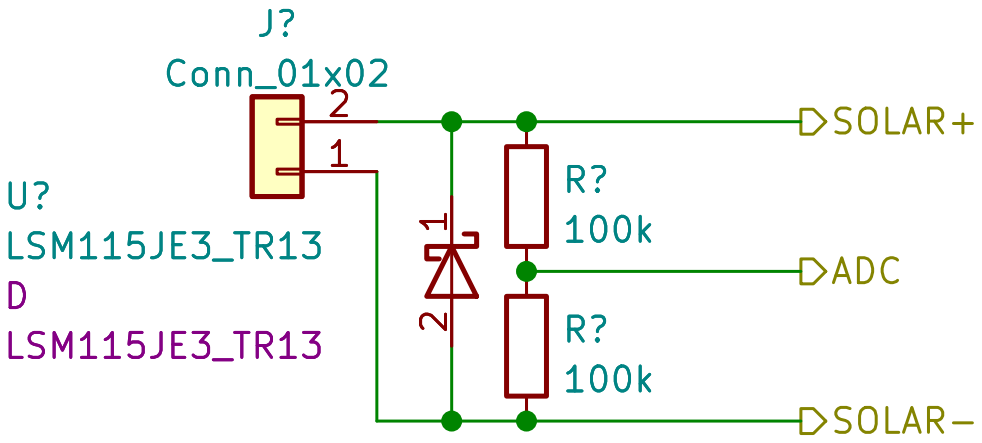
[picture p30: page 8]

File: Solar_Connector.kicad_sch Sheet: /Solar_Connector1/ e-mail: Author: Carlos Martinez Mora

Id: 8/12 Title: EPS Schematics

File: Solar_Connector.kicad_sch Sheet: /Solar_Connector2/ e-mail: Author: Carlos Martinez Mora

Id: 9/12 Title: EPS Schematics

File: Solar_Connector.kicad_sch Sheet: /Solar_Connector3/ e-mail: Author: Carlos Martinez Mora

Id: 10/12 Title: EPS Schematics

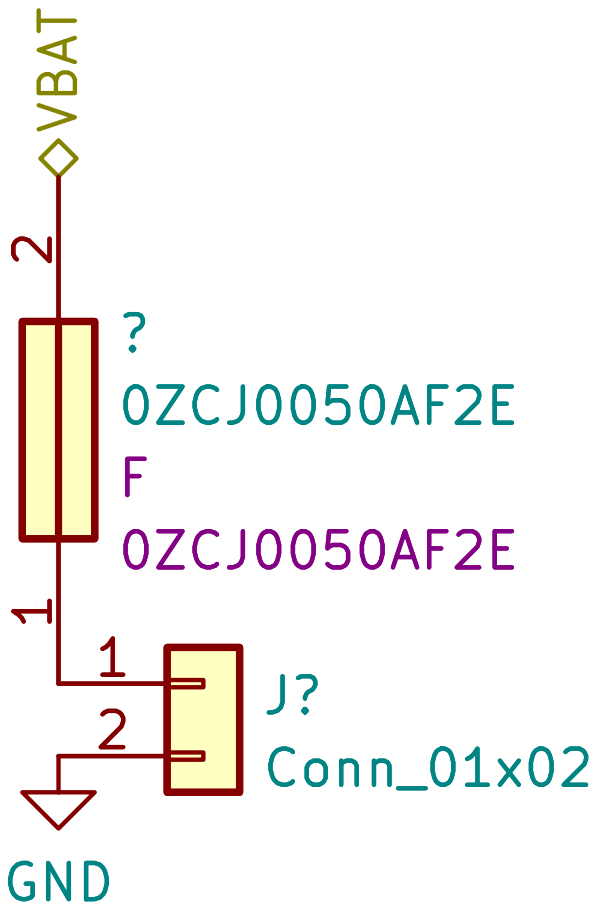
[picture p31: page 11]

File: Battery_Connector.kicad_sch Sheet: /Battery_Connector/ e-mail: Author: Carlos Martinez Mora

Id: 11/12 Title: EPS Schematics

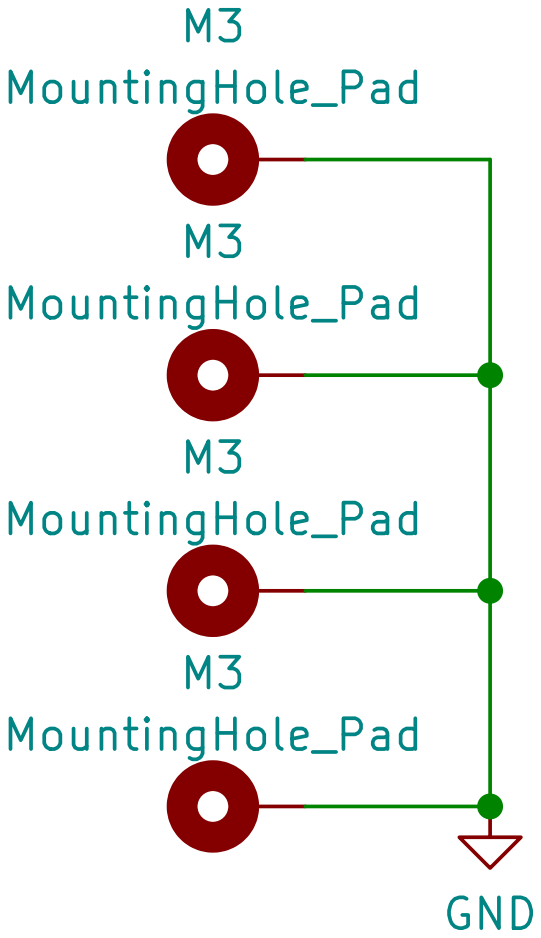
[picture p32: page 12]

Id: 12/12 Title: EPS Schematics

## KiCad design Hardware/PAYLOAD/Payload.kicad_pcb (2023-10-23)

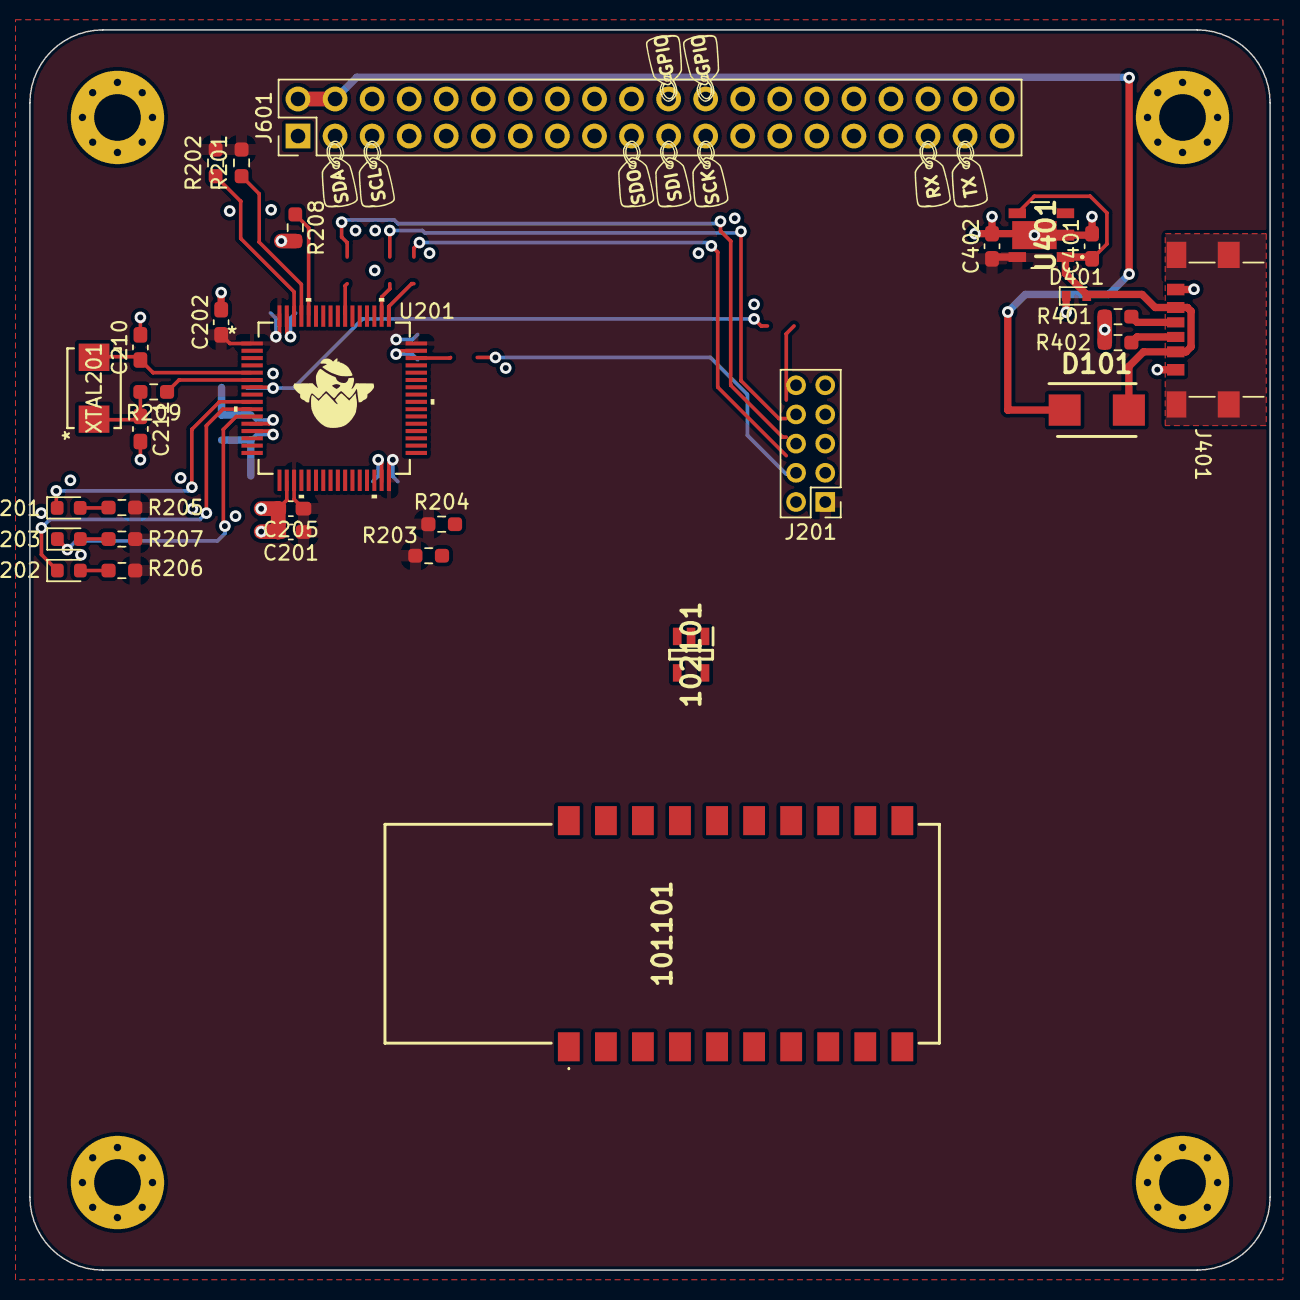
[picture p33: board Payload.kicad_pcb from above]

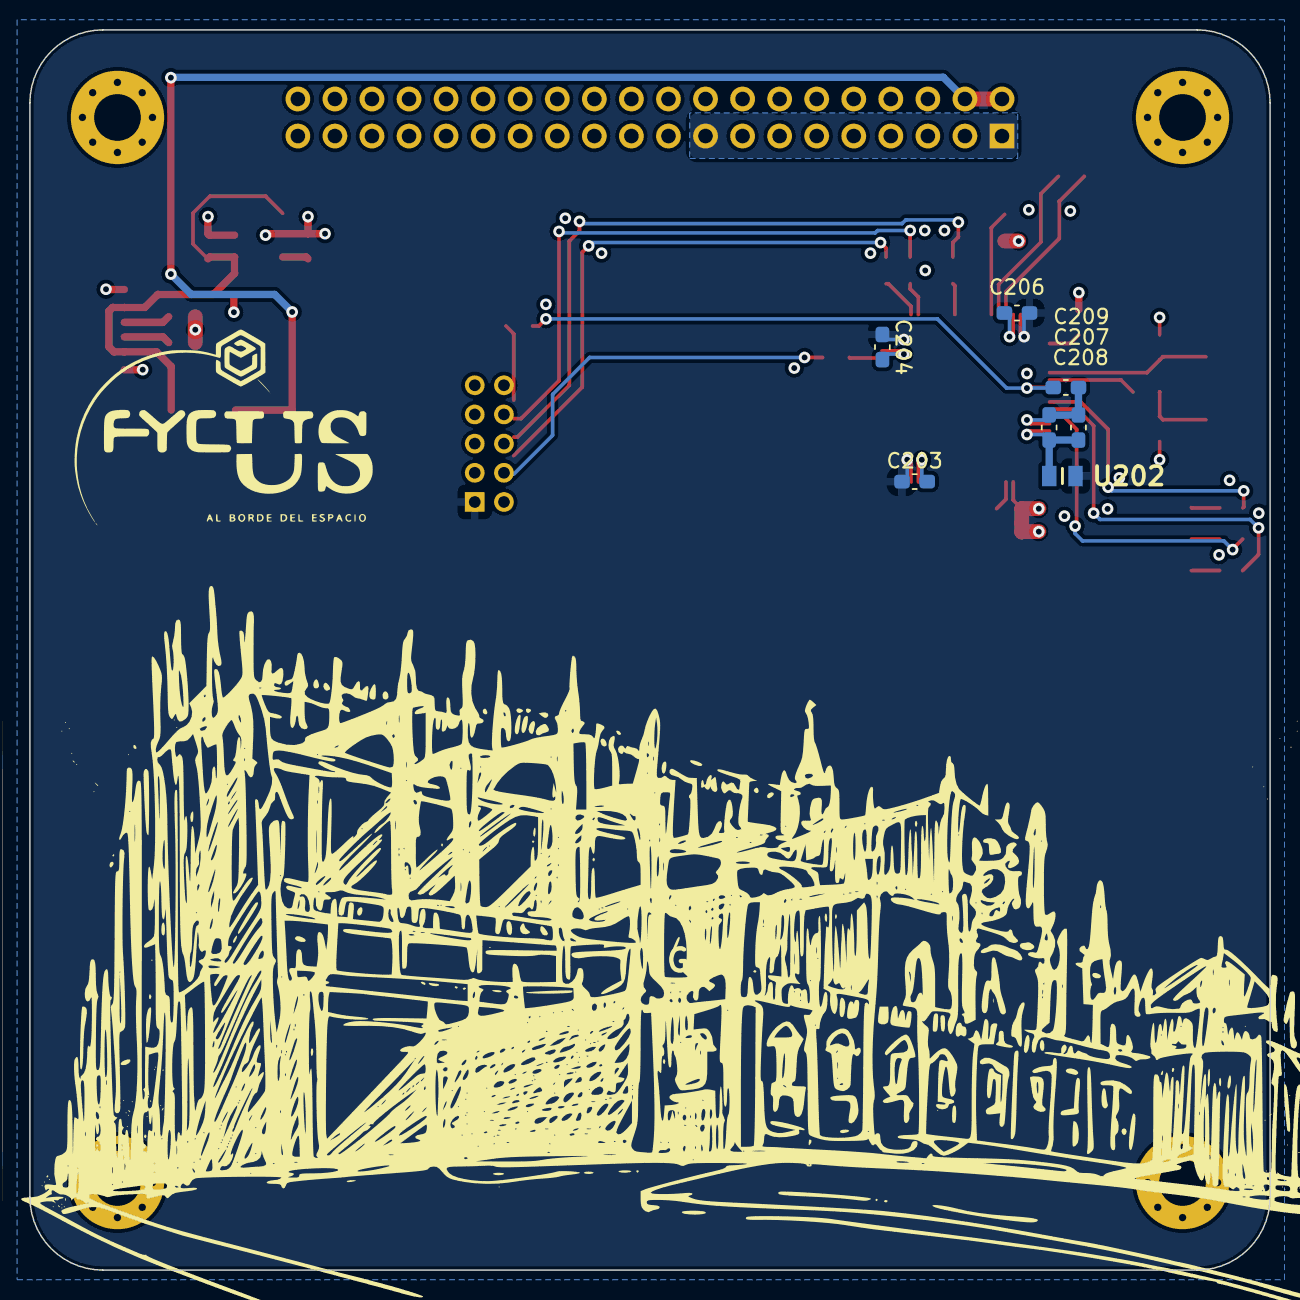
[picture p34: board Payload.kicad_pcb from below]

Board: 4 copper layers, 85.0 x 85.0 mm, 44 parts (8 on the bottom side), 27 nets.

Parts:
101101: RM-VT02; RMVT02
102101: LT1930ES5#TRMPBF; SOT95P280X145-5N
C201, C401, C402: 4.7uF; C_0603_1608Metric_Pad1.08x0.95mm_HandSolder
C202, C203, C204, C205, C206, C209: 100nF; C_0603_1608Metric_Pad1.08x0.95mm_HandSolder
C207: 1uF; C_0603_1608Metric_Pad1.08x0.95mm_HandSolder
C208: 10nF; C_0603_1608Metric_Pad1.08x0.95mm_HandSolder
C210, C211: 6pF; C_0603_1608Metric_Pad1.08x0.95mm_HandSolder
D101: LSM115JE3_TR13; DIOM5436X330N
D201: LED_R; LED_0603_1608Metric
D202: LED_G; LED_0603_1608Metric
D203: LED_B; LED_0603_1608Metric
D401: PESD5V0S1BB_115; D_SOD-523
G001, G002: LOGO
J201: Conn_ARM_JTAG_SWD_10; PinHeader_2x05_P2.00mm_Vertical
J401: USB_C_Receptacle_PowerOnly_6P; USB_C_Receptacle_GCT_USB4135-GF-A_6P_TopMnt_Horizontal
J601: Conn_02x20_Odd_Even; PinHeader_2x20_P2.54mm_Vertical
M1201, M1202, M1203, M1204: MountingHole_Pad; MountingHole_3.2mm_M3_Pad_Via
R201, R202, R203, R204: 4.7k; R_0603_1608Metric_Pad0.98x0.95mm_HandSolder
R205, R206: 130; R_0603_1608Metric_Pad0.98x0.95mm_HandSolder
R207: 120; R_0603_1608Metric_Pad0.98x0.95mm_HandSolder
R208: 10k; R_0603_1608Metric_Pad0.98x0.95mm_HandSolder
R209: 3.3k; R_0603_1608Metric_Pad0.98x0.95mm_HandSolder
R401, R402: 5.1k; R_0603_1608Metric_Pad0.98x0.95mm_HandSolder
U201: STM32L431RCT; LQFP-64
U202: HZ0805E601R-10; BEADC2012X90N
U401: AP7361C-33Y5-13; AP7361C25Y513
XTAL201: NX5032GA-8.000M-STD-CSU-1; XTAL_NX5032_NDK

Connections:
+3.3V: C201.1, C202.1, C203.1, C204.1, C205.1, C206.1, C402.1, J201.1 (VTref), R201.1, R202.2, R203.1, R204.2, R205.1, R206.1, R207.1, U201.1 (VBAT), U201.19 (VDD), U201.32 (VDD), U201.48 (VDD), U201.64 (VDD), U202.1, U401.5 (OUT)
+3.3VA: C207.1, C208.1, U201.13 (VDDA/VREF+), U202.2
+5V: D101.1 (K), J601.2, J601.4
/Board Connector/3.3V_PIN: J601.1, J601.17
/STM32 MCU/BOOT0: R208.1, U201.60 (PH3/BOOT0)
/STM32 MCU/HSE_IN: C210.1, U201.5 (RCC_OSC_IN), XTAL201.2
/STM32 MCU/HSE_OUT: R209.1, U201.6 (RCC_OSC_OUT)
/STM32 MCU/JTCK: J201.4 (SWDCLK/TCK), U201.49 (SYS_JTCK-SWCLK)
/STM32 MCU/JTDI: J201.8 (NC/TDI), U201.50 (SYS_JTDI)
/STM32 MCU/JTDO: J201.6 (SWO/TDO), U201.55 (SYS_JTDO-SWO)
/STM32 MCU/JTMS: J201.2 (SWDIO/TMS), U201.46 (SYS_JTMS-SWDIO)
/STM32 MCU/LED_G: D202.1 (K), U201.10 (ADC1_IN3)
/STM32 MCU/LED_R: D201.1 (K), U201.9 (ADC1_IN2)
/STM32 MCU/LED_YL: D203.1 (K), U201.11 (ADC1_IN4)
/STM32 MCU/NRST: C209.1, J201.10 (~RESET), U201.7 (NRST)
/STM32 MCU/SCL1: R201.2, U201.61 (PB8)
/STM32 MCU/SCL2: R203.2, U201.34 (I2C2_SCL)
/STM32 MCU/SDA1: R202.1, U201.62 (PB9)
/STM32 MCU/SDA2: R204.1, U201.35 (I2C2_SDA)
/USB Power/USB_VBUS: C401.1, D101.2 (A), D401.2 (A2), J401.A9 (VBUS), J401.B9 (VBUS), U401.1 (EN), U401.4 (IN)
GND: C201.2, C202.2, C203.2, C204.2, C205.2, C206.2, C207.2, C208.2, C209.2, C210.2, C211.2, C401.2, C402.2, D401.1 (A1), J201.3 (GND), J201.5 (GND), J201.9 (GNDDetect), J401.A12 (GND), J401.B12 (GND), J601.6, J601.9, J601.14, J601.20, J601.25, J601.30, J601.34, J601.39, M1201.1, M1202.1, M1203.1, M1204.1, R208.2, R401.2, R402.2, U201.12 (VSSA/VREF-), U201.18 (VSS), U201.31 (VSS), U201.47 (VSS), U201.63 (VSS), U401.2 (GND_1), U401.6 (GND_2)
unnamed: C211.1, R209.2, XTAL201.1
unnamed: D201.2 (A), R205.2
unnamed: D202.2 (A), R206.2
unnamed: D203.2 (A), R207.2
unnamed: J401.A5 (CC1), R402.1
unnamed: J401.B5 (CC2), R401.1

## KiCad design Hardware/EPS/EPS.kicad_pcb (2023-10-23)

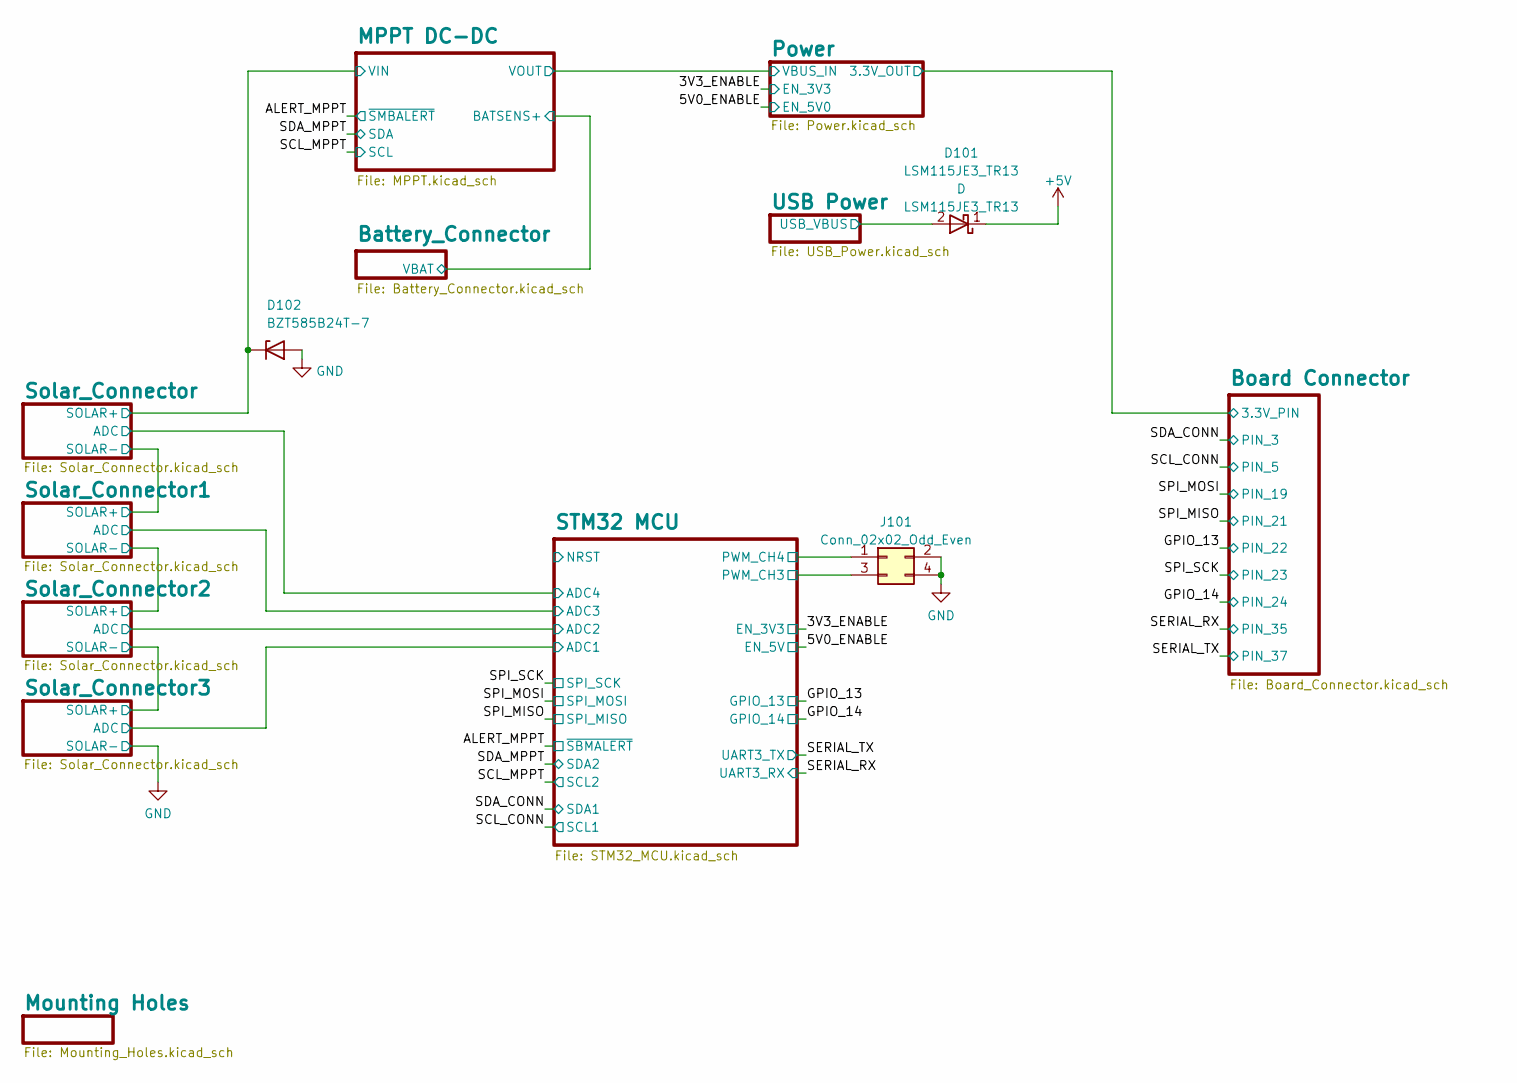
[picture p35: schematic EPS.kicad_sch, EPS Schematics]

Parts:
D101: LSM115JE3_TR13; DIOM5436X330N; Manufacturer_Part_Number LSM115JE3/TR13; Mouser Part Number 494-LSM115JE3/TR13
D102: BZT585B24T-7; D_SOD-523
J101: Conn_02x02_Odd_Even; PinHeader_2x02_P2.54mm_Vertical

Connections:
+5V: D101.1 (K); also elsewhere on the board
/MPPT DC-DC/VIN: D102.1 (K); also elsewhere on the board
/STM32 MCU/PWM_CH3: J101.3; also elsewhere on the board
/STM32 MCU/PWM_CH4: J101.1; also elsewhere on the board
/USB Power/USB_VBUS: D101.2 (A); also elsewhere on the board
GND: D102.2 (A), J101.2, J101.4; also elsewhere on the board

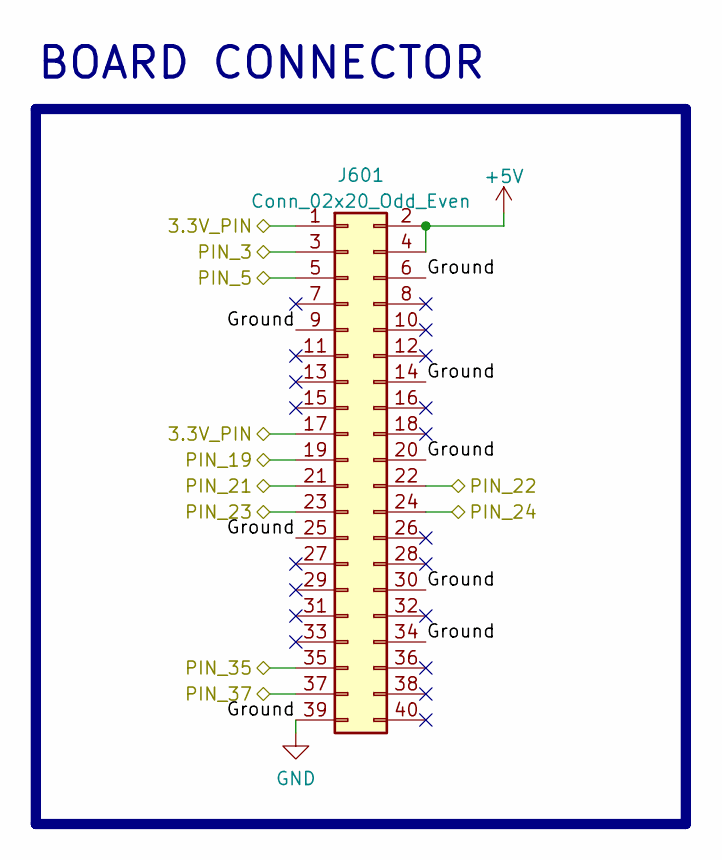
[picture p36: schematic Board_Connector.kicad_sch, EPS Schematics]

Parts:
J601: Conn_02x20_Odd_Even; PinHeader_2x20_P2.54mm_Vertical

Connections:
+5V: J601.2, J601.4; also elsewhere on the board
/Board Connector/3.3V_PIN: J601.1, J601.17; also elsewhere on the board
/GPIO_13: J601.22; also elsewhere on the board
/GPIO_14: J601.24; also elsewhere on the board
/SCL_CONN: J601.5; also elsewhere on the board
/SDA_CONN: J601.3; also elsewhere on the board
/SERIAL_RX: J601.35; also elsewhere on the board
/SERIAL_TX: J601.37; also elsewhere on the board
/SPI_MISO: J601.21; also elsewhere on the board
/SPI_MOSI: J601.19; also elsewhere on the board
/SPI_SCK: J601.23; also elsewhere on the board
GND: J601.6, J601.9, J601.14, J601.20, J601.25, J601.30, J601.34, J601.39; also elsewhere on the board

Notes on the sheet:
BOARD CONNECTOR

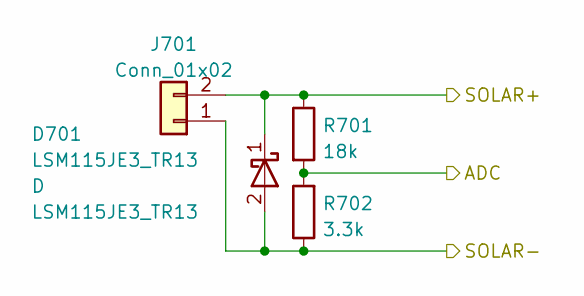
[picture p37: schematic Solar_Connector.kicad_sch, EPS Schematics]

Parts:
D701: LSM115JE3_TR13; DIOM5436X330N; Manufacturer_Part_Number LSM115JE3/TR13; Mouser Part Number 494-LSM115JE3/TR13
J701: Conn_01x02; JST_PH_S2B-PH-K_1x02_P2.00mm_Horizontal
R701: 18k; R_0603_1608Metric_Pad0.98x0.95mm_HandSolder
R702: 3.3k; R_0603_1608Metric_Pad0.98x0.95mm_HandSolder

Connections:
/MPPT DC-DC/VIN: D701.1 (K), J701.2, R701.1; also elsewhere on the board
/STM32 MCU/ADC4: R701.2, R702.2; also elsewhere on the board
/Solar_Connector/SOLAR-: D701.2 (A), J701.1, R702.1; also elsewhere on the board

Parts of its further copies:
D801, D901, D1001: LSM115JE3_TR13; DIOM5436X330N; Manufacturer_Part_Number LSM115JE3/TR13; Mouser Part Number 494-LSM115JE3/TR13
J801, J901, J1001: Conn_01x02; JST_PH_S2B-PH-K_1x02_P2.00mm_Horizontal
R801, R901, R1001: 18k; R_0603_1608Metric_Pad0.98x0.95mm_HandSolder
R802, R902, R1002: 3.3k; R_0603_1608Metric_Pad0.98x0.95mm_HandSolder

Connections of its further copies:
/STM32 MCU/ADC1: R1001.2, R1002.2; also elsewhere on the board
/STM32 MCU/ADC2: R901.2, R902.2; also elsewhere on the board
/STM32 MCU/ADC3: R801.2, R802.2; also elsewhere on the board
/Solar_Connector1/SOLAR-: D801.2 (A), D901.1 (K), J801.1, J901.2, R802.1, R901.1
/Solar_Connector2/SOLAR-: D901.2 (A), D1001.1 (K), J901.1, J1001.2, R902.1, R1001.1
/Solar_Connector/SOLAR-: D801.1 (K), J801.2, R801.1; also elsewhere on the board
GND: D1001.2 (A), J1001.1, R1002.1; also elsewhere on the board

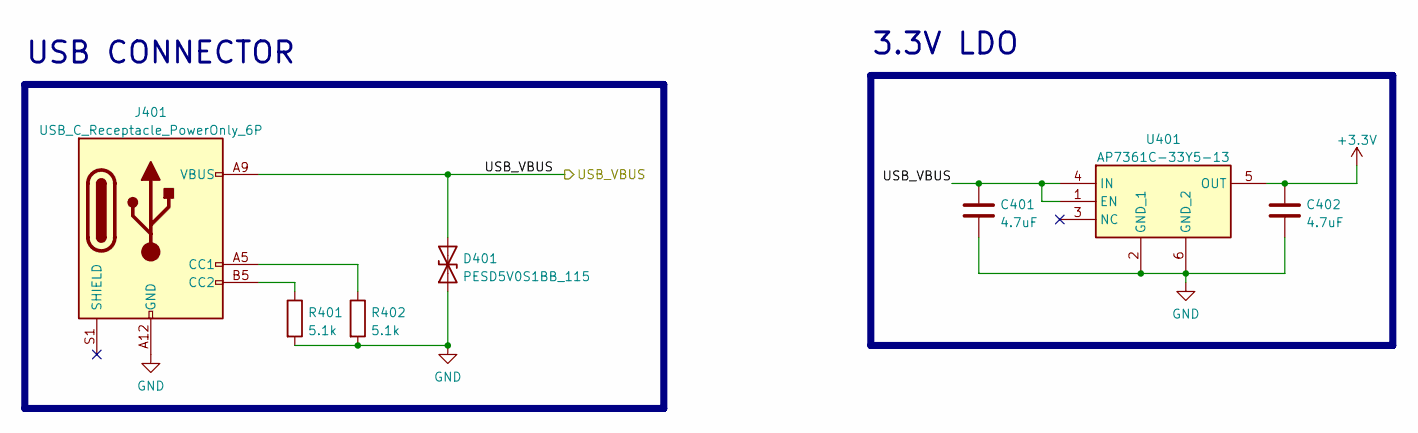
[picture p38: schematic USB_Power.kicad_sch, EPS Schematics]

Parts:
C401, C402: 4.7uF; C_0603_1608Metric_Pad1.08x0.95mm_HandSolder
D401: PESD5V0S1BB_115; D_SOD-523
J401: USB_C_Receptacle_PowerOnly_6P; USB_C_Receptacle_GCT_USB4135-GF-A_6P_TopMnt_Horizontal
R401, R402: 5.1k; R_0603_1608Metric_Pad0.98x0.95mm_HandSolder
U401: AP7361C-33Y5-13; AP7361C25Y513; Manufacturer_Part_Number AP7361C-25Y5-13; Mouser Part Number 621-AP7361C-25Y5-13

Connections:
+3.3V: C402.1, U401.5 (OUT); also elsewhere on the board
/USB Power/USB_VBUS: C401.1, D401.2 (A2), J401.A9 (VBUS), J401.B9 (VBUS), U401.1 (EN), U401.4 (IN); also elsewhere on the board
GND: C401.2, C402.2, D401.1 (A1), J401.A12 (GND), J401.B12 (GND), R401.2, R402.2, U401.2 (GND_1), U401.6 (GND_2); also elsewhere on the board
unnamed: J401.A5 (CC1), R402.1
unnamed: J401.B5 (CC2), R401.1

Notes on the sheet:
USB CONNECTOR
3.3V LDO

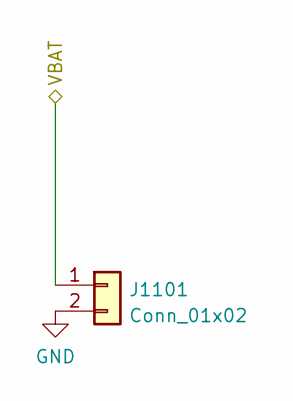
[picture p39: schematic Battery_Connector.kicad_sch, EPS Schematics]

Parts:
J1101: Conn_01x02; JST_PH_S2B-PH-K_1x02_P2.00mm_Horizontal

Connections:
/Battery_Connector/VBAT: J1101.1; also elsewhere on the board
GND: J1101.2; also elsewhere on the board

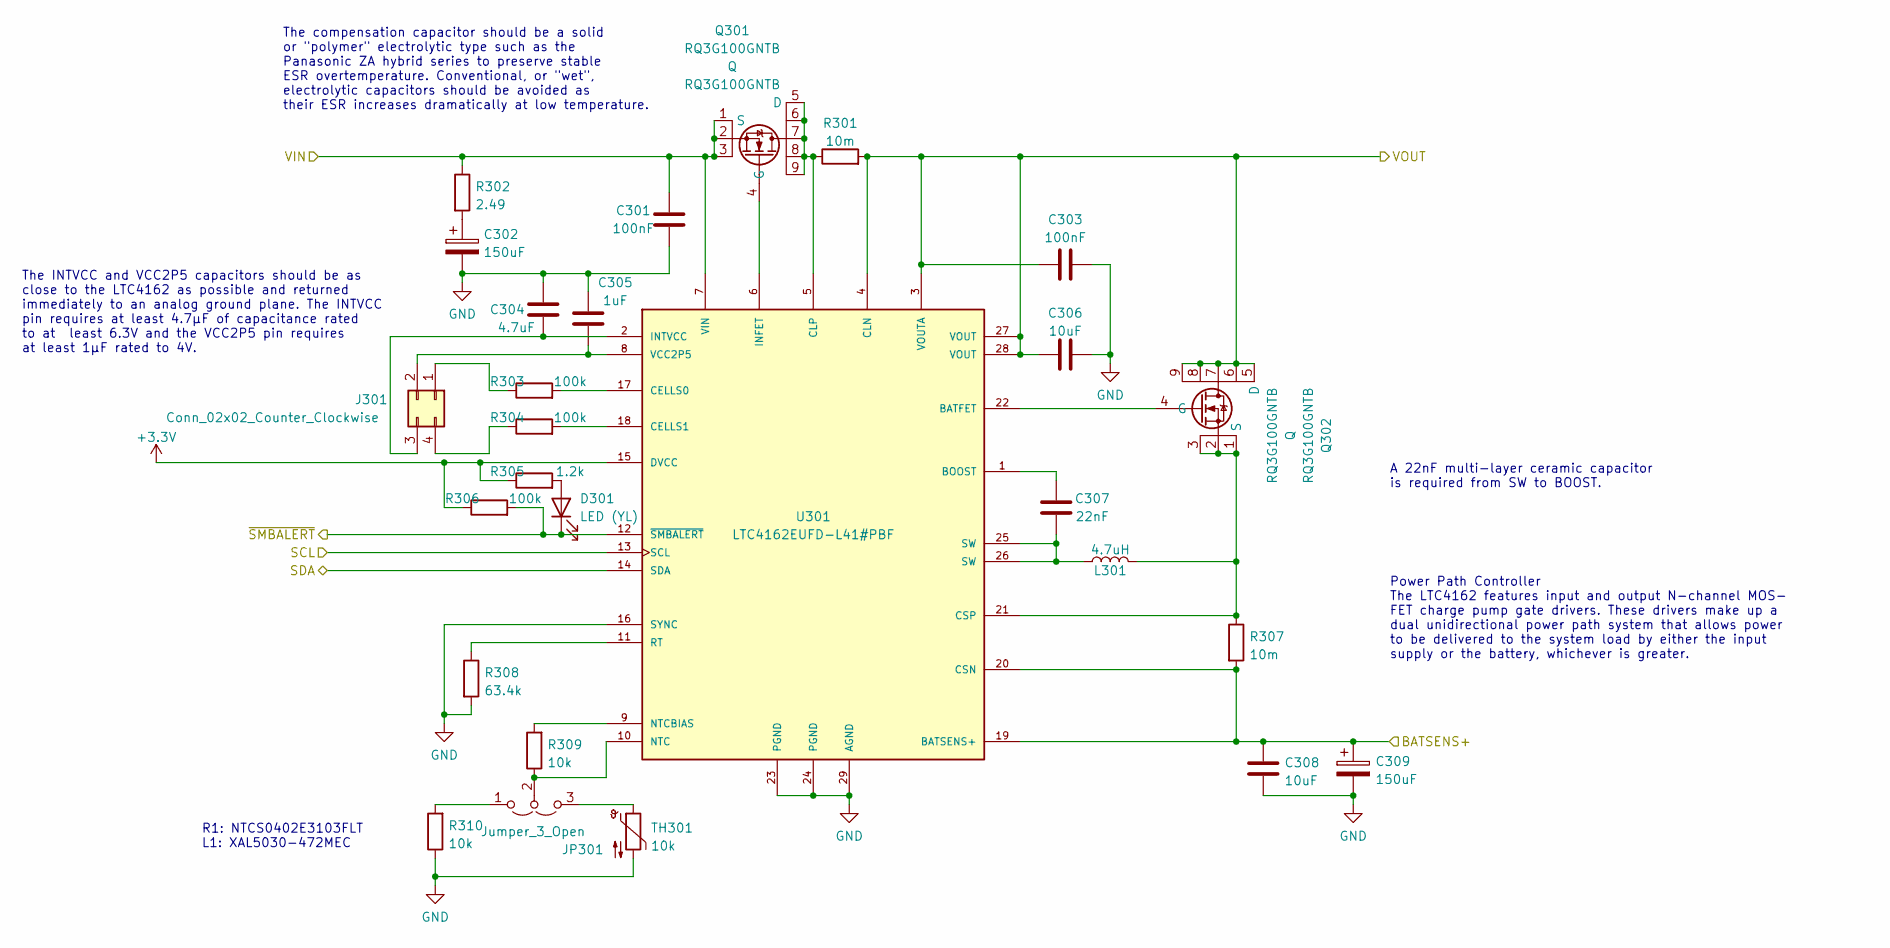
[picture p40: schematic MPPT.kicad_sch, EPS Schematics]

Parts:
C301, C303: 100nF; C_0603_1608Metric_Pad1.08x0.95mm_HandSolder
C302, C309: 150uF; CAP_EEHZS1H151V
C304: 4.7uF; C_0603_1608Metric_Pad1.08x0.95mm_HandSolder
C305: 1uF; C_0603_1608Metric_Pad1.08x0.95mm_HandSolder
C306, C308: 10uF; C_1206_3216Metric_Pad1.33x1.80mm_HandSolder
C307: 22nF; C_0603_1608Metric_Pad1.08x0.95mm_HandSolder
D301: LED (YL); LED_0603_1608Metric
J301: Conn_02x02_Counter_Clockwise; PinHeader_2x02_P2.54mm_Vertical
JP301: Jumper_3_Open; PinHeader_1x03_P2.54mm_Vertical
L301: 4.7uH; XAL1060222MEB
Q301, Q302: RQ3G100GNTB; Mouser Part Number 755-RQ3G100GNTB
R301, R307: 10m; R_0805_2012Metric_Pad1.20x1.40mm_HandSolder
R302: 2.49; R_1206_3216Metric_Pad1.30x1.75mm_HandSolder
R303, R304, R306: 100k; R_0603_1608Metric_Pad0.98x0.95mm_HandSolder
R305: 1.2k; R_0603_1608Metric_Pad0.98x0.95mm_HandSolder
R308: 63.4k; R_0603_1608Metric_Pad0.98x0.95mm_HandSolder
R309, R310: 10k; R_0603_1608Metric_Pad0.98x0.95mm_HandSolder
TH301: 10k; PinHeader_1x02_P1.00mm_Vertical
U301: LTC4162EUFD-L41#PBF; QFN50P500X400X80-29N; PARTREV A

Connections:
+3.3V: R305.1, R306.1, U301.15 (DVCC); also elsewhere on the board
/ALERT_MPPT: D301.1 (K), R306.2, U301.12 (~SMBALERT); also elsewhere on the board
/Battery_Connector/VBAT: C308.1, C309.1, R307.2, U301.19 (BATSENS+), U301.20 (CSN); also elsewhere on the board
/MPPT DC-DC/VIN: C301.1, Q301.1 (S), Q301.2, Q301.3, R302.1, U301.7 (VIN); also elsewhere on the board
/MPPT DC-DC/VOUT: C303.1, C306.1, Q302.5 (D), Q302.6, Q302.7, Q302.8, Q302.9, R301.2, U301.3 (VOUTA), U301.4 (CLN), U301.27 (VOUT), U301.28 (VOUT); also elsewhere on the board
/SCL_MPPT: U301.13 (SCL); also elsewhere on the board
/SDA_MPPT: U301.14 (SDA); also elsewhere on the board
GND: C301.2, C302.2, C303.2, C304.2, C305.2, C306.2, C308.2, C309.2, R308.2, R310.1, TH301.2, U301.16 (SYNC), U301.23 (PGND), U301.24 (PGND), U301.29 (AGND); also elsewhere on the board
unnamed: C302.1, R302.2
unnamed: C304.1, J301.3, U301.2 (INTVCC)
unnamed: C305.1, J301.2, U301.8 (VCC2P5)
unnamed: C307.1, U301.1 (BOOST)
unnamed: C307.2, L301.1, U301.25 (SW), U301.26 (SW)
unnamed: D301.2 (A), R305.2
unnamed: J301.1, R303.1
unnamed: J301.4, R304.1
unnamed: JP301.1 (A), R310.2
unnamed: JP301.2 (C), R309.1, U301.10 (NTC)
unnamed: JP301.3 (B), TH301.1
unnamed: L301.2, Q302.1 (S), Q302.2, Q302.3, R307.1, U301.21 (CSP)
unnamed: Q301.4 (G), U301.6 (INFET)
unnamed: Q301.5 (D), Q301.6, Q301.7, Q301.8, Q301.9, R301.1, U301.5 (CLP)
unnamed: Q302.4 (G), U301.22 (BATFET)
unnamed: R303.2, U301.17 (CELLS0)
unnamed: R304.2, U301.18 (CELLS1)
unnamed: R308.1, U301.11 (RT)
unnamed: R309.2, U301.9 (NTCBIAS)

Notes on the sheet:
The INTVCC and VCC2P5 capacitors should be as close to the LTC4162 as possible and returned immediately to an analog ground plane. The INTVCC pin requires at least 4.7μF of capacitance rated to at least 6.3V and the VCC2P5 pin requires at least 1μF rated to 4V.
A 22nF multi-layer ceramic capacitor is required from SW to BOOST.
Power Path Controller The LTC4162 features input and output N-channel MOS- FET charge pump gate drivers. These drivers make up a dual unidirectional power path system that allows power to be delivered to the system load by either the input supply or the battery, whichever is greater.
R1: NTCS0402E3103FLT L1: XAL5030-472MEC
The compensation capacitor should be a solid or "polymer" electrolytic type such as the Panasonic ZA hybrid series to preserve stable ESR overtemperature. Conventional, or "wet", electrolytic capacitors should be avoided as their ESR increases dramatically at low temperature.

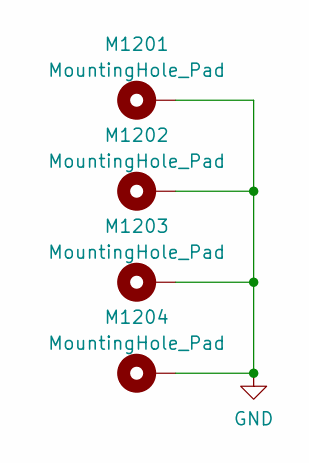
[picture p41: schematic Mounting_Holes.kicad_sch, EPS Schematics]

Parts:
M1201, M1202, M1203, M1204: MountingHole_Pad; MountingHole_3.2mm_M3_Pad_Via

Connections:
GND: M1201.1, M1202.1, M1203.1, M1204.1; also elsewhere on the board

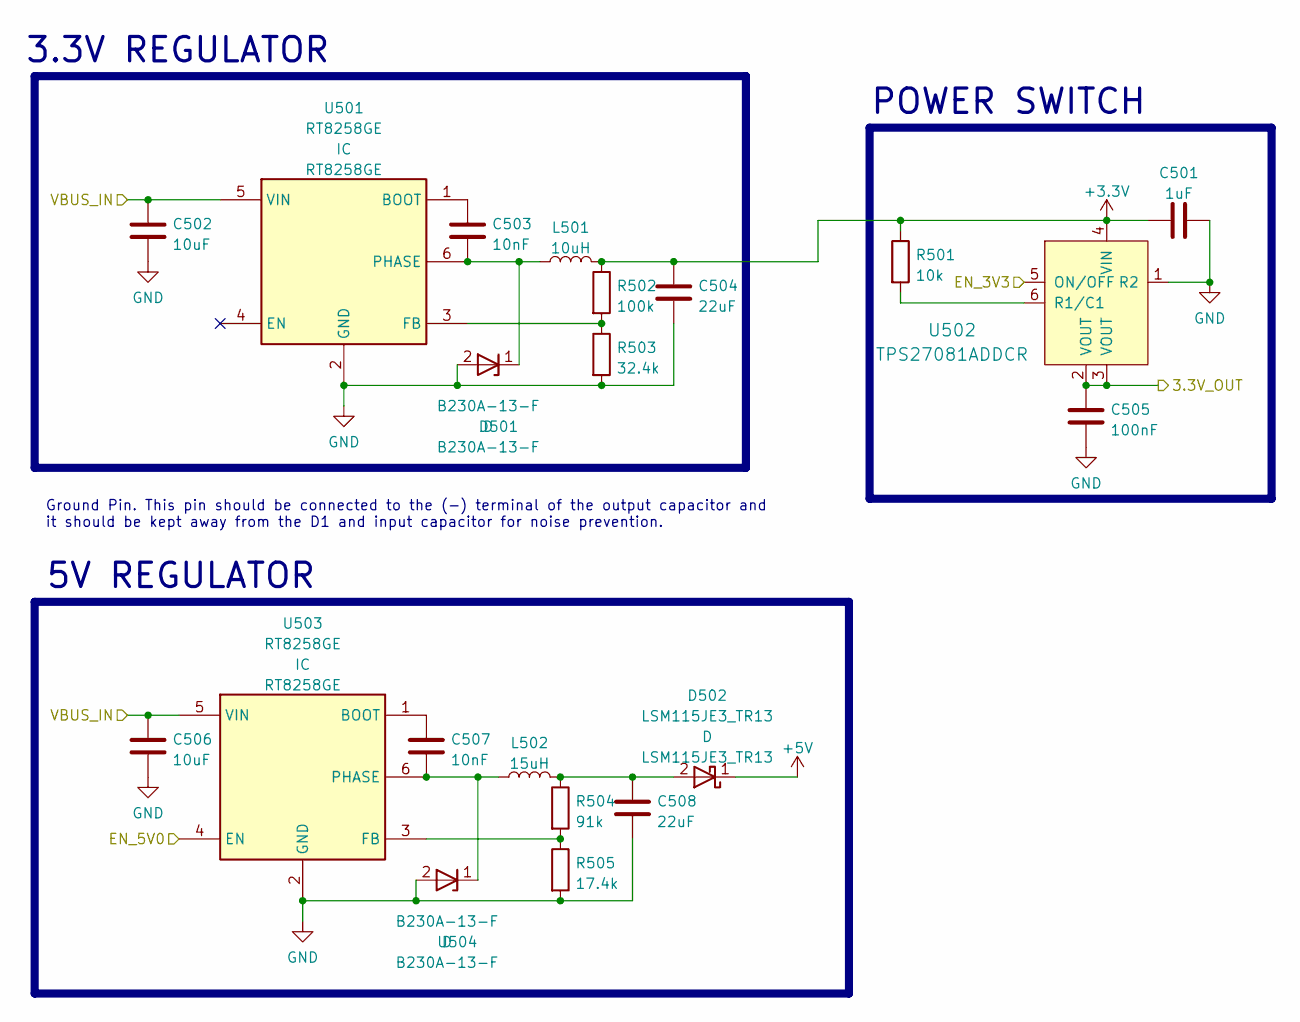
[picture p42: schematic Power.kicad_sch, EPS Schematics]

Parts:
C501: 1uF; C_0603_1608Metric_Pad1.08x0.95mm_HandSolder
C502, C506: 10uF; C_0603_1608Metric_Pad1.08x0.95mm_HandSolder
C503, C507: 10nF; C_0603_1608Metric_Pad1.08x0.95mm_HandSolder
C504, C508: 22uF; C_0603_1608Metric_Pad1.08x0.95mm_HandSolder
C505: 100nF; C_0603_1608Metric_Pad1.08x0.95mm_HandSolder
D501: B230A-13-F; DIOM5226X230N; Manufacturer_Part_Number B230A-13-F; Mouser Part Number 621-B230A-F
D502: LSM115JE3_TR13; DIOM5436X330N; Manufacturer_Part_Number LSM115JE3/TR13; Mouser Part Number 494-LSM115JE3/TR13
L501: 10uH; SLF12555T
L502: 15uH; SLF12565
R501: 10k; R_0603_1608Metric_Pad0.98x0.95mm_HandSolder
R502: 100k; R_0603_1608Metric_Pad0.98x0.95mm_HandSolder
R503: 32.4k; R_0603_1608Metric_Pad0.98x0.95mm_HandSolder
R504: 91k; R_0603_1608Metric_Pad0.98x0.95mm_HandSolder
R505: 17.4k; R_0603_1608Metric_Pad0.98x0.95mm_HandSolder
U501, U503: RT8258GE; SOT94P279X130-6N; Manufacturer_Part_Number RT8258GE
U502: TPS27081ADDCR; SOT-23-6; MPN TPS27081ADDCR; Digi-Key_PN 296-34970-1-ND
U504: B230A-13-F; DIOM5226X230N; Manufacturer_Part_Number B230A-13-F; Mouser Part Number 621-B230A-F

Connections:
+3.3V: C501.2, C504.1, L501.2, R501.1, R502.1, U502.4 (VIN); also elsewhere on the board
+5V: D502.1 (K); also elsewhere on the board
/3V3_ENABLE: U502.5 (ON/OFF); also elsewhere on the board
/5V0_ENABLE: U503.4 (EN); also elsewhere on the board
/Board Connector/3.3V_PIN: C505.1, U502.2 (VOUT), U502.3 (VOUT); also elsewhere on the board
/MPPT DC-DC/VOUT: C502.1, C506.1, U501.5 (VIN), U503.5 (VIN); also elsewhere on the board
GND: C501.1, C502.2, C504.2, C505.2, C506.2, C508.2, D501.2 (A), R503.2, R505.2, U501.2 (GND), U502.1 (R2), U503.2 (GND), U504.2 (A); also elsewhere on the board
unnamed: C503.1, U501.1 (BOOT)
unnamed: C503.2, D501.1 (K), L501.1, U501.6 (PHASE)
unnamed: C507.1, U503.1 (BOOT)
unnamed: C507.2, L502.1, U503.6 (PHASE), U504.1 (K)
unnamed: C508.1, D502.2 (A), L502.2, R504.1
unnamed: R501.2, U502.6 (R1/C1)
unnamed: R502.2, R503.1, U501.3 (FB)
unnamed: R504.2, R505.1, U503.3 (FB)

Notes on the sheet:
3.3V REGULATOR
POWER SWITCH
Ground Pin. This pin should be connected to the (-) terminal of the output capacitor and it should be kept away from the D1 and input capacitor for noise prevention.
5V REGULATOR

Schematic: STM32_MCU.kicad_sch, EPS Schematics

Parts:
C201: 4.7uF; C_0603_1608Metric_Pad1.08x0.95mm_HandSolder
C202, C203, C204, C205, C208: 100nF; C_0603_1608Metric_Pad1.08x0.95mm_HandSolder
C206: 1uF; C_0603_1608Metric_Pad1.08x0.95mm_HandSolder
C207: 10nF; C_0603_1608Metric_Pad1.08x0.95mm_HandSolder
C210, C211: 6pF; C_0603_1608Metric_Pad1.08x0.95mm_HandSolder
D201: LED_R; LED_0603_1608Metric
D202: LED_G; LED_0603_1608Metric
D203: LED_YL; LED_0603_1608Metric
J201: Conn_ARM_JTAG_SWD_10; PinHeader_2x05_P2.00mm_Vertical
R201, R202, R203, R204: 4.7k; R_0603_1608Metric_Pad0.98x0.95mm_HandSolder
R205, R206: 130; R_0603_1608Metric_Pad0.98x0.95mm_HandSolder
R207: 120; R_0603_1608Metric_Pad0.98x0.95mm_HandSolder
R208: 10k; R_0603_1608Metric_Pad0.98x0.95mm_HandSolder
R209: 3.3k; R_0603_1608Metric_Pad0.98x0.95mm_HandSolder
U201: STM32L431RCT; LQFP-64
U202: HZ0805E601R-10; BEADC2012X90N; Manufacturer_Part_Number HZ0805E601R-10
Y201: NX5032GA-8.000M-STD-CSU-1; XTAL_NX5032_NDK

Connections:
+3.3V: C201.1, C202.1, C203.1, C204.1, C205.1, J201.1 (VTref), R201.1, R202.2, R203.1, R204.2, R205.1, R206.1, R207.1, U201.1 (VBAT), U201.19 (VDD), U201.32 (VDD), U201.48 (VDD), U201.64 (VDD), U202.1; also elsewhere on the board
/3V3_ENABLE: U201.41 (PA8); also elsewhere on the board
/5V0_ENABLE: U201.40 (PC9); also elsewhere on the board
/ALERT_MPPT: U201.36 (PB15); also elsewhere on the board
/GPIO_13: U201.2 (PC13); also elsewhere on the board
/GPIO_14: U201.3 (PC14-OSC32_IN); also elsewhere on the board
/SCL_CONN: R201.2, U201.61 (PB8); also elsewhere on the board
/SCL_MPPT: R203.2, U201.34 (I2C2_SCL); also elsewhere on the board
/SDA_CONN: R202.1, U201.62 (PB9); also elsewhere on the board
/SDA_MPPT: R204.1, U201.35 (I2C2_SDA); also elsewhere on the board
/SERIAL_RX: U201.52 (PC11); also elsewhere on the board
/SERIAL_TX: U201.51 (PC10); also elsewhere on the board
/SPI_MISO: U201.44 (PA11); also elsewhere on the board
/SPI_MOSI: U201.45 (PA12); also elsewhere on the board
/SPI_SCK: U201.15 (PA1); also elsewhere on the board
/STM32 MCU/ADC1: U201.22 (PA6); also elsewhere on the board
/STM32 MCU/ADC2: U201.23 (PA7); also elsewhere on the board
/STM32 MCU/ADC3: U201.24 (PC4); also elsewhere on the board
/STM32 MCU/ADC4: U201.25 (PC5); also elsewhere on the board
/STM32 MCU/BOOT0: R208.1, U201.60 (PH3/BOOT0)
/STM32 MCU/HSE_IN: C210.1, U201.5 (RCC_OSC_IN), Y201.2
/STM32 MCU/HSE_OUT: R209.1, U201.6 (RCC_OSC_OUT)
/STM32 MCU/JTCK: J201.4 (SWDCLK/TCK), U201.49 (SYS_JTCK-SWCLK)
/STM32 MCU/JTDI: J201.8 (NC/TDI), U201.50 (SYS_JTDI)
/STM32 MCU/JTDO: J201.6 (SWO/TDO), U201.55 (SYS_JTDO-SWO)
/STM32 MCU/JTMS: J201.2 (SWDIO/TMS), U201.46 (SYS_JTMS-SWDIO)
/STM32 MCU/LED_G: D202.1 (K), U201.10 (ADC1_IN3)
/STM32 MCU/LED_R: D201.1 (K), U201.9 (ADC1_IN2)
/STM32 MCU/LED_YL: D203.1 (K), U201.11 (ADC1_IN4)
/STM32 MCU/PWM_CH3: U201.29 (PB10); also elsewhere on the board
/STM32 MCU/PWM_CH4: U201.30 (PB11); also elsewhere on the board
GND: C201.2, C202.2, C203.2, C204.2, C205.2, C206.2, C207.2, C208.2, C210.2, C211.2, J201.3 (GND), J201.5 (GND), J201.9 (GNDDetect), R208.2, U201.12 (VSSA/VREF-), U201.18 (VSS), U201.31 (VSS), U201.47 (VSS), U201.63 (VSS); also elsewhere on the board
unnamed: C211.1, R209.2, Y201.1
unnamed: D201.2 (A), R205.2
unnamed: D202.2 (A), R206.2
unnamed: D203.2 (A), R207.2

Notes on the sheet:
Rext must be 3316 Ohms aprox. so resistor measurement is advised to get as close as possible.
HSE CRYSTAL RESONATOR
BOOT PULL-DOWN
LEDS
I2C PULL-UPS
STM32 MCU
DECOUPLING
JTAG

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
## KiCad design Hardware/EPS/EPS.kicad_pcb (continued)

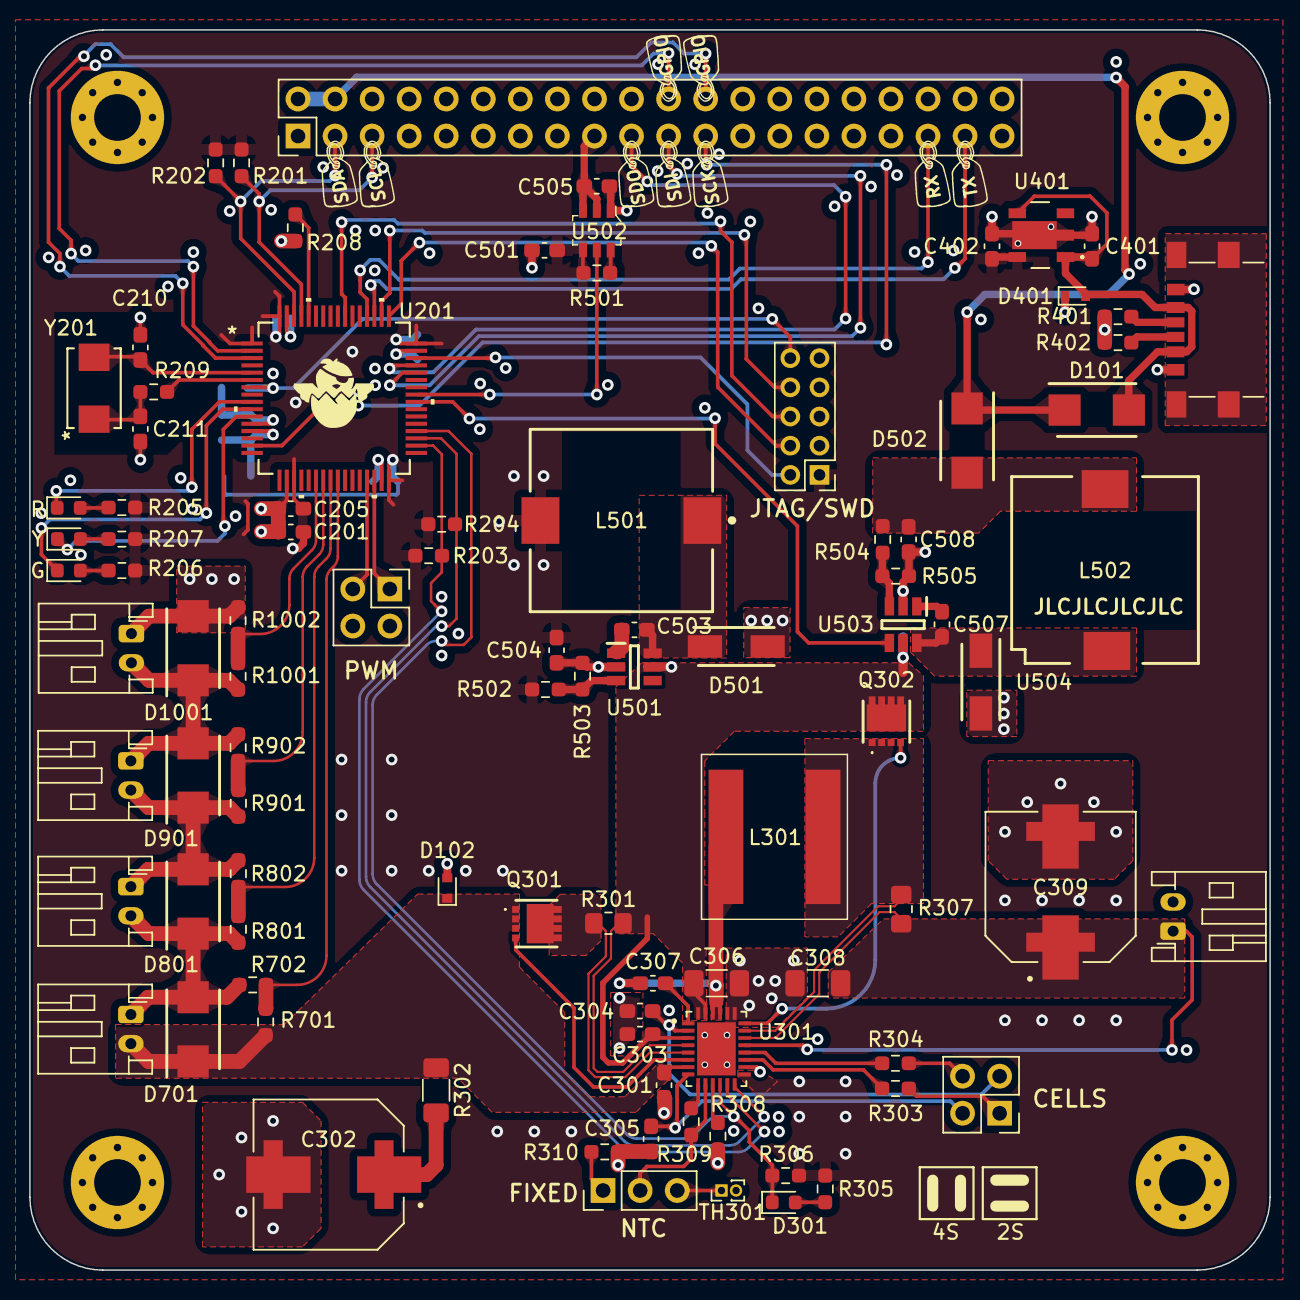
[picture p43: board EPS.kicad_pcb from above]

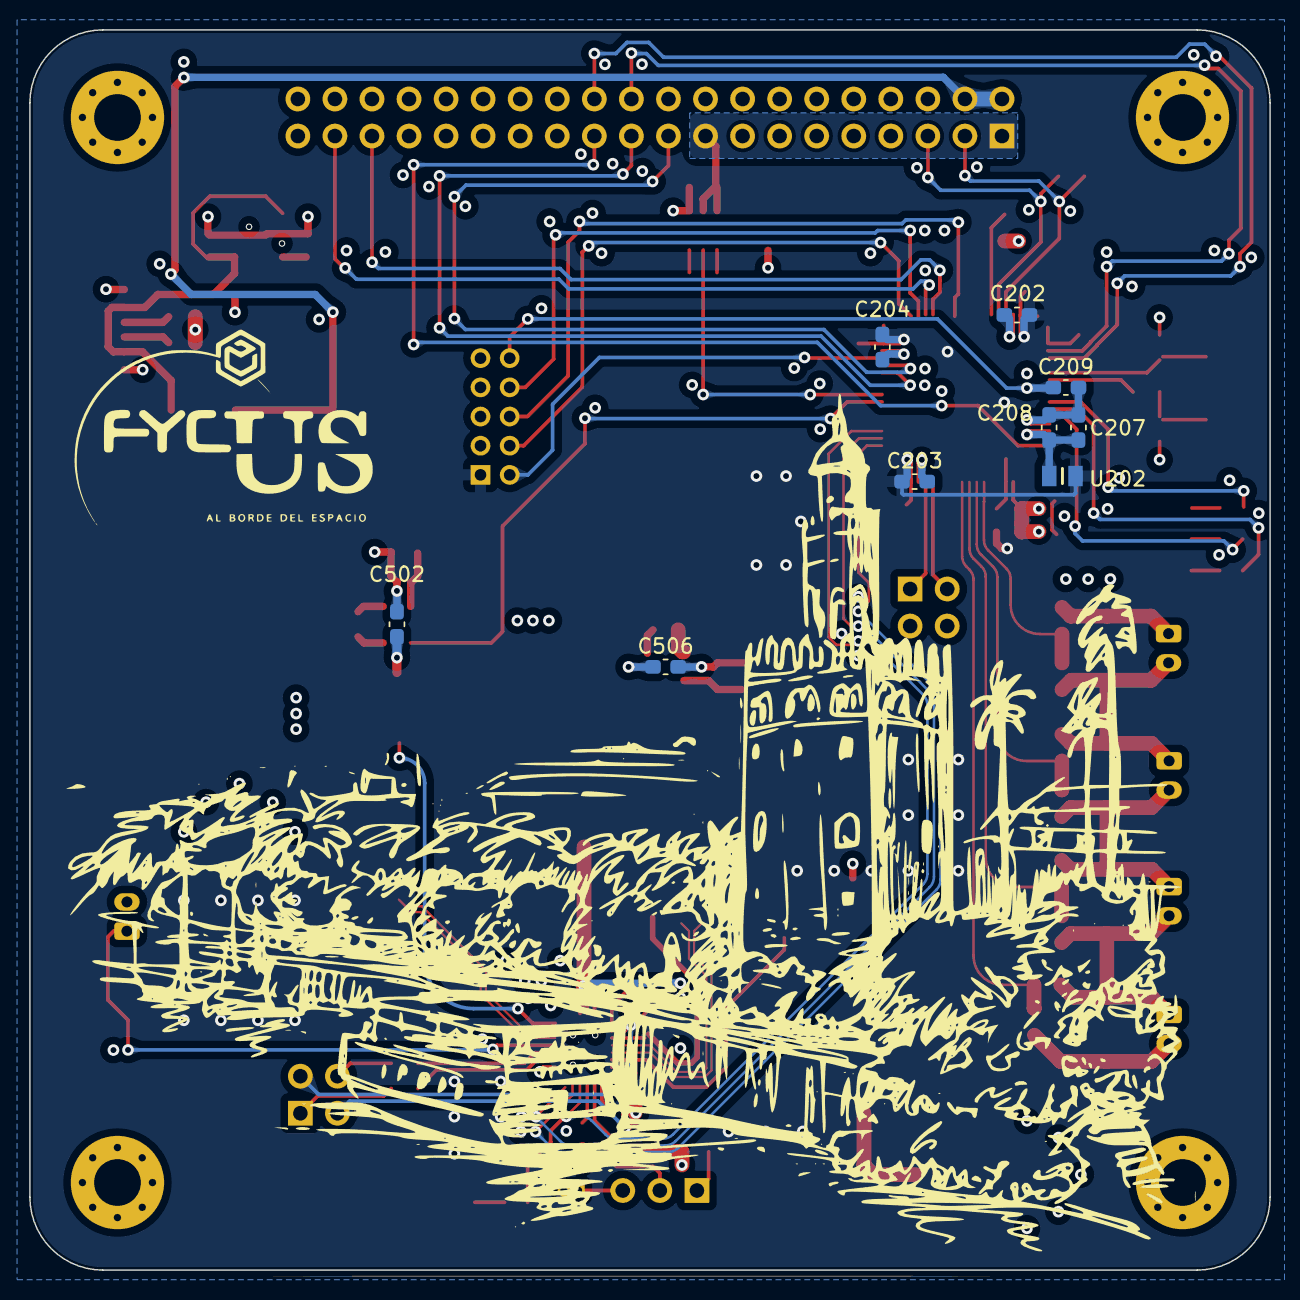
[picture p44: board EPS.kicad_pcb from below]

Board: 4 copper layers, 85.0 x 85.0 mm, 108 parts (10 on the bottom side), 76 nets.

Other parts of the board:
C209: 100nF; C_0603_1608Metric_Pad1.08x0.95mm_HandSolder
G001, G002: LOGO

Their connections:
GND: C209.2; also elsewhere on the board

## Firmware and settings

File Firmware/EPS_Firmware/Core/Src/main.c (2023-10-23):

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
/* Includes ------------------------------------------------------------------*/
#include "main.h"
#include "cmsis_os.h"

/* USER CODE BEGIN Includes */
#include "EPS_FYCUS.h"
#include "LTC4162.h"
#include "LTC4162-LAD_reg_defs.h"
#include"LTC4162-LAD_formats.h"
#include "bus_packet.h"
#include <stdbool.h>
#include <string.h>
#include <stdio.h>
#include <stdlib.h>

/* USER CODE END Includes */

CRC_HandleTypeDef hcrc;

I2C_HandleTypeDef hi2c1;
I2C_HandleTypeDef hi2c2;

SPI_HandleTypeDef hspi1;

TIM_HandleTypeDef htim2;

UART_HandleTypeDef huart3;

/* Definitions for MPPT_IC */
osThreadId_t MPPT_ICHandle;
const osThreadAttr_t MPPT_IC_attributes = {
  .name = "MPPT_IC",
  .stack_size = 512 * 4,
  .priority = (osPriority_t) osPriorityLow,
};
/* Definitions for ReportStatus */
osThreadId_t ReportStatusHandle;
const osThreadAttr_t ReportStatus_attributes = {
  .name = "ReportStatus",
  .stack_size = 1024 * 4,
  .priority = (osPriority_t) osPriorityLow,
};
/* Definitions for PowerRails */
osThreadId_t PowerRailsHandle;
const osThreadAttr_t PowerRails_attributes = {
  .name = "PowerRails",
  .stack_size = 128 * 4,
  .priority = (osPriority_t) osPriorityLow,
};
/* USER CODE BEGIN PV */
static EPS_Telemetry telemetry;
static uint8_t buf[4];
static uint8_t buf[BUS_PACKET_BUS_SIZE];



/* USER CODE END PV */

void SystemClock_Config(void);
static void MX_GPIO_Init(void);
static void MX_I2C1_Init(void);
static void MX_I2C2_Init(void);
static void MX_TIM2_Init(void);
static void MX_SPI1_Init(void);
static void MX_USART3_UART_Init(void);
static void MX_CRC_Init(void);
void prvMonitorMPPT(void *argument);
void prvSendTelemetry(void *argument);
void prvPowerManagement(void *argument);

/**
  * @brief  The application entry point.
  * @retval int
  */
int main(void)
{
  /* MCU Configuration--------------------------------------------------------*/

  /* Reset of all peripherals, Initializes the Flash interface and the Systick. */
  HAL_Init();

  /* Configure the system clock */
  SystemClock_Config();

  /* Initialize all configured peripherals */
  MX_GPIO_Init();
  MX_I2C1_Init();
  MX_I2C2_Init();
  MX_TIM2_Init();
  MX_SPI1_Init();
  MX_USART3_UART_Init();
  MX_CRC_Init();
  /* Init scheduler */
  osKernelInitialize();

  /* USER CODE BEGIN RTOS_MUTEX */
  /* add mutexes, ... */
  /* USER CODE END RTOS_MUTEX */

  /* USER CODE BEGIN RTOS_SEMAPHORES */
  /* add semaphores, ... */
  /* USER CODE END RTOS_SEMAPHORES */

  /* USER CODE BEGIN RTOS_TIMERS */
  /* start timers, add new ones, ... */
  /* USER CODE END RTOS_TIMERS */

  /* USER CODE BEGIN RTOS_QUEUES */
  /* add queues, ... */
  /* USER CODE END RTOS_QUEUES */

  /* Create the thread(s) */
  /* creation of MPPT_IC */
  MPPT_ICHandle = osThreadNew(prvMonitorMPPT, NULL, &MPPT_IC_attributes);

  /* creation of ReportStatus */
  ReportStatusHandle = osThreadNew(prvSendTelemetry, NULL, &ReportStatus_attributes);

  /* creation of PowerRails */
  PowerRailsHandle = osThreadNew(prvPowerManagement, NULL, &PowerRails_attributes);

  /* USER CODE BEGIN RTOS_THREADS */
  /* add threads, ... */
  /* USER CODE END RTOS_THREADS */

  /* USER CODE BEGIN RTOS_EVENTS */
  /* add events, ... */
  /* USER CODE END RTOS_EVENTS */

  /* Start scheduler */
  osKernelStart();

  /* We should never get here as control is now taken by the scheduler */
  /* Infinite loop */
  /* USER CODE BEGIN WHILE */
  while (1)
  {
    /* USER CODE END WHILE */

    /* USER CODE BEGIN 3 */
  }
  /* USER CODE END 3 */
}

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
/* USER CODE BEGIN 4 */

void HAL_UARTEx_RxEventCallback(UART_HandleTypeDef *huart, uint16_t Size)
{
//	osThreadFlagsSet(ReportStatusHandle, 0x1U);
	HAL_UARTEx_ReceiveToIdle_IT(&huart3, (uint8_t *)buf, 4);
}

void HAL_UART_TxCpltCallback(UART_HandleTypeDef *huart)
{
	osThreadFlagsSet(ReportStatusHandle, 0x2U);
}

/* USER CODE END 4 */

/* USER CODE BEGIN Header_prvMonitorMPPT */
/**
  * @brief  Function implementing the MPPT_IC thread. In charge of configuring, and monitoring
  * the MPPT IC - LTC4162
  * @param  argument: Not used
  * @retval None
  */
/* USER CODE END Header_prvMonitorMPPT */
void prvMonitorMPPT(void *argument)
{
  /* USER CODE BEGIN 5 */

	LTC4162_Init(&hi2c2);

	/* Infinite loop */
	for(;;)
	{
		HAL_GPIO_TogglePin(LED_G_GPIO_Port, LED_G_Pin);

		LTC4162_GetReg(LTC4162_VIN, &telemetry.v_in);

		LTC4162_GetReg(LTC4162_VOUT, &telemetry.v_out);

		LTC4162_GetReg(LTC4162_VBAT, &telemetry.v_bat);

		LTC4162_GetReg(LTC4162_IBAT, &telemetry.i_bat);

		LTC4162_GetReg(LTC4162_IIN, &telemetry.i_in);

		LTC4162_GetReg(LTC4162_DIE_TEMP, &telemetry.die_temp);

		LTC4162_GetReg(LTC4162_THERMISTOR_VOLTAGE, &telemetry.thermistor_voltage);

		LTC4162_GetReg(LTC4162_BSR, &telemetry.bsr);

		LTC4162_GetReg(LTC4162_CHARGER_STATE, &telemetry.charger_state);


		osDelay(100);
	}
  /* USER CODE END 5 */
}

/* USER CODE BEGIN Header_prvSendTelemetry */
/**
* @brief Function implementing the ReportStatus thread.
* @param argument: Not used
* @retval None
*/
/* USER CODE END Header_prvSendTelemetry */
void prvSendTelemetry(void *argument)
{
  /* USER CODE BEGIN prvSendTelemetry */

	memcpy(buf, BUS_PACKET_FRAME_SYNC, 4);

	/* Infinite loop */
	for(;;)
	{
		HAL_GPIO_TogglePin(LED_G_GPIO_Port, LED_G_Pin);

//		do {
//			osThreadFlagsWait(0x1U, osFlagsWaitAll, osWaitForever);
//		} while (buf != 0xDEAD);
		bus_packet_EncodePacketize(BUS_PACKET_TYPE_TM, 0x40, BUS_PACKET_ECF_EXIST, (uint8_t *)&telemetry, sizeof(telemetry), buf + 4);

		HAL_UART_Transmit(&huart3, buf, bus_packet_GetLength(buf + 4) + 4,1000);
//		osThreadFlagsWait(0x2U, osFlagsWaitAny, osWaitForever);


		osDelay(5000);
	}
  /* USER CODE END prvSendTelemetry */
}

/* USER CODE BEGIN Header_prvPowerManagement */
/**
* @brief Function implementing the PowerRails thread.
* @param argument: Not used
* @retval None
*/
/* USER CODE END Header_prvPowerManagement */
void prvPowerManagement(void *argument)
{
  /* USER CODE BEGIN prvPowerManagement */
	/* Infinite loop */
	for(;;)
	{
		HAL_GPIO_TogglePin(LED_G_GPIO_Port, LED_G_Pin);

		HAL_GPIO_WritePin(EN_3V3_GPIO_Port, EN_3V3_Pin, GPIO_PIN_SET);

		osThreadSuspend(PowerRailsHandle);

	}
  /* USER CODE END prvPowerManagement */
}

/**
  * @brief  Period elapsed callback in non blocking mode
  * @note   This function is called  when TIM1 interrupt took place, inside
  * HAL_TIM_IRQHandler(). It makes a direct call to HAL_IncTick() to increment
  * a global variable "uwTick" used as application time base.
  * @param  htim : TIM handle
  * @retval None
  */
void HAL_TIM_PeriodElapsedCallback(TIM_HandleTypeDef *htim)
{
  if (htim->Instance == TIM1) {
    HAL_IncTick();
  }
}

/**
  * @brief  This function is executed in case of error occurrence.
  * @retval None
  */
void Error_Handler(void)
{
  /* USER CODE BEGIN Error_Handler_Debug */
  /* User can add his own implementation to report the HAL error return state */
  __disable_irq();
  while (1)
  {
	  HAL_GPIO_TogglePin(LED_R_GPIO_Port, LED_R_Pin);
	  HAL_Delay(250);
  }
  /* USER CODE END Error_Handler_Debug */
}

#ifdef  USE_FULL_ASSERT
/**
  * @brief  Reports the name of the source file and the source line number
  *         where the assert_param error has occurred.
  * @param  file: pointer to the source file name
  * @param  line: assert_param error line source number
  * @retval None
  */
void assert_failed(uint8_t *file, uint32_t line)
{
  /* USER CODE BEGIN 6 */
  /* User can add his own implementation to report the file name and line number,
     ex: printf("Wrong parameters value: file %s on line %d\r\n", file, line) */
  /* USER CODE END 6 */
}
#endif /* USE_FULL_ASSERT */

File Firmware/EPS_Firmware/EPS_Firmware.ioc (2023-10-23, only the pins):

Mcu.UserName=STM32L431RCTx
PA1.Signal=SPI1_SCK
PA11.Signal=SPI1_MISO
PA12.Signal=SPI1_MOSI
PA8.GPIO_Label=EN_3V3
PA8.Signal=GPIO_Output
PB10.Signal=S_TIM2_CH3
PB11.Signal=S_TIM2_CH4
PB13.Signal=I2C2_SCL
PB14.Signal=I2C2_SDA
PB15.GPIO_Label=SBMALERT
PB15.Signal=GPXTI15
PB8.Signal=I2C1_SCL
PB9.Signal=I2C1_SDA
PC1.GPIO_Label=LED_R
PC1.Signal=GPIO_Output
PC10.Signal=USART3_TX
PC11.Signal=USART3_RX
PC13.Signal=GPXTI13
PC2.GPIO_Label=LED_G
PC2.Signal=GPIO_Output
PC3.GPIO_Label=LED_YL
PC3.Signal=GPIO_Output
PC9.GPIO_Label=EN_5V
PC9.Signal=GPIO_Output

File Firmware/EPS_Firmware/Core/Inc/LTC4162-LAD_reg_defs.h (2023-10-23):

/*!
LTC4162: Advanced Synchronous Switching Battery Charger and PowerPath Manager

@verbatim
The LTC®4162-L is an advanced synchronous switching battery charger and
PowerPath manager that seamlessly manages power distribution from input sources
such as wall adapters, backplanes, solar panels, etc. and a rechargeable
battery. A high resolution telemetry system provides extensive information on
circuit voltages, currents, battery resistance and temperatures which can all be
read back over the serial interface. The serial interface can also be used to
configure many of the charging parameters including termination algorithms as
well as numerous system status alerts. The LTC4162-L can charge Lithium-Ion cell
stacks as high as eight cells with up to 3.2A of charge current. The power path
topology decouples the output voltage from the battery allowing a portable
product to start up under very low battery voltage conditions. The LTC4162-L is
available in an I²C adjustable version as well as 4.0V, 4.1V and 4.2V fixed
voltage versions all with and without MPPT enabled by default. The LTC4162-L is
available in the 28-pin 4mm × 5mm × 0.75mm QFN surface mount package.
@endverbatim

http://www.linear.com/product/LTC4162

http://www.linear.com/product/LTC4162#demoboards

REVISION HISTORY
$Revision: 1758 $
$Date: 2018-02-15 14:28:32 -0500 (Thu, 15 Feb 2018) $

Copyright (c) 2018, Linear Technology Corp.(LTC)
All rights reserved.

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
1.  Redistributions  of source code must retain the above copyright notice, this
    list  of conditions and the following disclaimer.

2.  Redistributions  in  binary  form must reproduce the above copyright notice,
    this  list of conditions and  the following disclaimer in the  documentation
    and/or other materials provided with the distribution.

THIS  SOFTWARE IS PROVIDED BY THE COPYRIGHT HOLDERS AND CONTRIBUTORS "AS IS" AND
ANY  EXPRESS  OR  IMPLIED WARRANTIES, INCLUDING, BUT NOT LIMITED TO, THE IMPLIED
WARRANTIES   OF  MERCHANTABILITY  AND  FITNESS  FOR  A  PARTICULAR  PURPOSE  ARE
DISCLAIMED.  IN NO EVENT SHALL THE COPYRIGHT OWNER OR CONTRIBUTORS BE LIABLE FOR
ANY  DIRECT,  INDIRECT, INCIDENTAL, SPECIAL, EXEMPLARY, OR CONSEQUENTIAL DAMAGES
(INCLUDING,  BUT  NOT  LIMITED  TO, PROCUREMENT OF SUBSTITUTE GOODS OR SERVICES;
LOSS  OF  USE, DATA, OR PROFITS; OR BUSINESS INTERRUPTION) HOWEVER CAUSED AND ON
ANY  THEORY  OF  LIABILITY,  WHETHER  IN  CONTRACT,  STRICT  LIABILITY,  OR TORT
(INCLUDING  NEGLIGENCE  OR  OTHERWISE) ARISING IN ANY WAY OUT OF THE USE OF THIS
SOFTWARE, EVEN IF ADVISED OF THE POSSIBILITY OF SUCH DAMAGE.

The  views and conclusions contained in the software and documentation are those
of  the authors and should not be interpreted as representing official policies,
either expressed or implied, of Linear Technology Corp.

The Linear Technology Linduino is not affiliated with the official Arduino team.
However,  the Linduino is only possible because of the Arduino team's commitment
to   the   open-source   community.   Please,  visit  http://www.arduino.cc  and
http://store.arduino.cc,  and consider  a purchase  that  will  help fund  their
ongoing work.

Generated on: 2018-01-19
*/

/*! @file
 *  @ingroup LTC4162-LAD
 *  @brief LTC4162-LAD Register Map Definition Header
 *
 *
 *  This file contains LTC4162 definitions for each command_code as well as
 *  each individual bit field for the case when a register contains multiple
 *  bit-packed fields smaller than the register width.
 *
 *  Each bit field name is prepended with LTC4162_.
 *  Each bit field has individual definitions for its _SIZE, _OFFSET (LSB) and _MASK,
 *  as well as the three fields stored in a single 16-bit word for use with the access
 *  functions provided by LTC4162-LAD.c and LTC4162-LAD.h.
 *
 *  Additionally, each bit field contains a _DECODE macro to unpack multiple individual
 *  bit fields from a single copy of complete register data.
 *
 *  In the case that the bit field contents represent an enumeration, _ENUM
 *  definitions exist to translate from human readable format to the encoded value.
 *
 *  In the case that the bit field contents represent scalar data,
 *  macros exist in LTC4162_formats.h to translate from real units to integer values and back again.
 *  Real to integer conversions of literals should generally be optimized away at compile time
 *  without impact on execution speed or code size.
 *
 *  See @ref LTC4162-LAD_register_map for detailed descriptions of each bit field.
 *  See @ref LTC4162-LAD_formats for detailed descriptions of each data formatting macro.
 */

/*! @defgroup LTC4162-LAD_register_map LTC4162 Register Map Definitions
 *  @ingroup LTC4162-LAD
 */

#ifndef LTC4162_REG_DEFS_H_
#define LTC4162_REG_DEFS_H_

#define LTC4162_ADDR_68 0x68 << 1 //!<LTC4162 I2C address in 7-bit format

#define LTC4162_WORD_SIZE 16
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

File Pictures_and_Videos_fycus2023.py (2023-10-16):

#Códig para tomar fotos y vídeos espaciados en tiempo usando
#múltiples cámaras raspi y usb
#FYCUS 2023
#autor: Juan C.
#fecha: 16/09/2023

#LIBRERIAS
#RaspiCam
from picamera2 import Picamera2, Preview
from picamera2.encoders import H264Encoder
import time
#Usb cam & files creation
import os
import datetime
###########

first_directory = "/home/raspberryfycus/Desktop/Fotos_y_videos/"
os.chdir(first_directory)
foldername = datetime.datetime.now().strftime("%Y-%m-%d-%H.%M.%S")
#crear carpeta nueva donde guardar fotos y videos
os.mkdir(f"{foldername}")
#mover directorio de trabajo a carpeta nueva
directory = "/home/raspberryfycus/Desktop/Fotos_y_videos/{}".format(foldername)
os.chdir(directory)

#crear log de fallos
log_name = "{}_error_log.txt".format(foldername)
log_file = open(log_name,"w+")

n_pictures = range(5)


#bucle infinito

while True:
########################## RASPICAM ####################

    try:
        ########take a picture
        picam = Picamera2()
        #Raspicam config
        photo_config = picam.create_still_configuration(main={"size": (3280, 2464)})
        picam.configure(photo_config)
    
        picam.start()
        for n in n_pictures:
            time.sleep(2)
            photoname = datetime.datetime.now() .strftime ("%Y-%m-%d-%H.%M.%S.jpg")
            picam.capture_file(photoname)
            time.sleep(5) #esperar 5 sec entre fotos
        picam.close()
    
    except:
        photoname = datetime.datetime.now() .strftime ("%Y-%m-%d-%H.%M.%S.jpg")
        error_name = "{} pi photo failed".format(datetime.datetime.now() .strftime ("%Y-%m-%d-%H.%M.%S.jpg"))
        log_file.write(error_name)
        log_file.write('\n')
############

    try:
        ##########make a video
        picam2 = Picamera2()
        video_config = picam2.create_video_configuration(main={"size": (1920, 1080)}, lores={"size": (640, 480)}, display="lores")
        picam2.configure(video_config)

        encoder = H264Encoder(10000000)

        videoname = datetime.datetime.now() .strftime ("%Y-%m-%d-%H.%M.%S.h264")
        picam2.start_recording(encoder, videoname)
        time.sleep(30) #30 second video
        picam2.stop_recording()
        picam2.close()
    except:
        error_name = "{} pi video failed".format(datetime.datetime.now() .strftime ("%Y-%m-%d-%H.%M.%S.jpg"))
        log_file.write(error_name)
        log_file.write('\n')
############

############
## USB PHOTO
    try:
        for n in n_pictures:
            usb_photo_input = "fswebcam -r 1920x1080 -S 3 --jpeg 50 --save {}/%Y-%m-%d-%H.%M.%S_usb.jpg".format(directory)
            os.system(usb_photo_input) # uses Fswebcam to take picture
            time.sleep(5) #esperar 5 sec entre fotos
    except:
        error_name = "{} usb photo failed".format(datetime.datetime.now() .strftime ("%Y-%m-%d-%H.%M.%S.jpg"))
        log_file.write(error_name)
        log_file.write('\n')
    
############
## USB VIDEO
    try:
        usb_videoname = datetime.datetime.now() .strftime ("%Y-%m-%d-%H.%M.%S_usbvideo.h264")
        usb_video_input = "ffmpeg -f v4l2 -t 00:00:30 -vcodec mjpeg -r 30 -video_size 1280x720 -i /dev/video0 {}/{}".format(directory,usb_videoname)
        os.system(usb_video_input)
    except:
        error_name = "{} usb video failed".format(datetime.datetime.now() .strftime ("%Y-%m-%d-%H.%M.%S.jpg"))
        log_file.write(error_name)
        log_file.write('\n')
    
    time.sleep(60) #esperar 1 minuto para repetir

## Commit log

2023-03-24 Added Project Files
    [EPS.kicad_pcb, EPS.kicad_sch]
2023-03-25 Edit README
    Fixing README
    Added LTC4162 footprint and symbol
    README Edit
    More README
    [EPS.kicad_sch]
2023-03-26 Created Schematic for LTC4162
    Added Comments
    [EPS.kicad_sch, MPPT.kicad_sch]
2023-03-26 Added USB, Solar Connector and MATLAB Folder
    [EPS.kicad_sch, MPPT.kicad_sch, Mounting_Holes.kicad_sch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]
2023-03-27 Added interboard connector and MCU
    [Board_Connector.kicad_sch, EPS.kicad_sch, MPPT.kicad_sch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]
2023-03-28 Added board connector layout
    [Board_Connector.kicad_sch, EPS.kicad_sch, MPPT.kicad_sch]
2023-04-02 IMU, GPS and Magnetometer blocks (Altium)
    [FC.PrjPcb, GPS_NEOM8M.SchDoc, IMU.SchDoc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]
2023-04-02 Added Power sheet and ESD Protection
    [EPS.kicad_sch, Power.kicad_sch, STM32_MCU.kicad_sch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]
2023-04-06 EPS v0.0.1
    [Battery_Connector.kicad_sch, EPS.kicad_sch, MPPT.kicad_sch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]
2023-04-08 Fuse, Power Switch to 3.3V, connector ESD Prot.
    v0.0.2
    [Battery_Connector.kicad_sch, Board_Connector.kicad_sch, EPS.kicad_sch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]
2023-04-09 Reworked LTC4162 Symbol
    [EPS.kicad_sch, MPPT.kicad_sch, Power.kicad_sch]
2023-04-09 Defined pinout for board connector, major revision
    v0.0.3 - Fixed erratas and cleaned the schematic
    [Battery_Connector.kicad_sch, Board_Connector.kicad_sch, EPS.kicad_sch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]
2023-04-13 MPPT IC Routing & layout
    [0530480210.stp, 1206L380SLTHYR.stp, 3220-10-0100-00.stp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]
2023-04-16 MPPT & Power layout finished
    [Battery_Connector.kicad_sch, Board_Connector.kicad_sch, EPS.kicad_pcb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]
2023-04-17 Changed uC pinout and finished uC routing
    [Board_Connector.kicad_sch, EPS.kicad_pcb, EPS.kicad_sch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]
2023-04-18 Finished XTAL layout
    [EPS.kicad_pcb]
2023-04-19 Finished EPS - v0.1.0
    [Battery_Connector.kicad_sch, Board_Connector.kicad_sch, EPS.kicad_pcb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]
2023-04-20 Created Payload Board
    [Board_Connector.kicad_sch, EPS.kicad_sch, LT1930ES5#TRMPBF.stp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]
2023-05-05 Updated to KiCAD 7.0
    [87831-1021.stp, Battery_Connector.kicad_sch, Board_Connector.kicad_sch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]
2023-08-04 Update, no changes. Blinky test on EPS HW
    [EPS-B_Cu.dxf, EPS-B_Mask.dxf, EPS-B_Paste.dxf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]
2023-10-15 Add files via upload
    Programa para hacer las fotos y vídeos con la raspberry

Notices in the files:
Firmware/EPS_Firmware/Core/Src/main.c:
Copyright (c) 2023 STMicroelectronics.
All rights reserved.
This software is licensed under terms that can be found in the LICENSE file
